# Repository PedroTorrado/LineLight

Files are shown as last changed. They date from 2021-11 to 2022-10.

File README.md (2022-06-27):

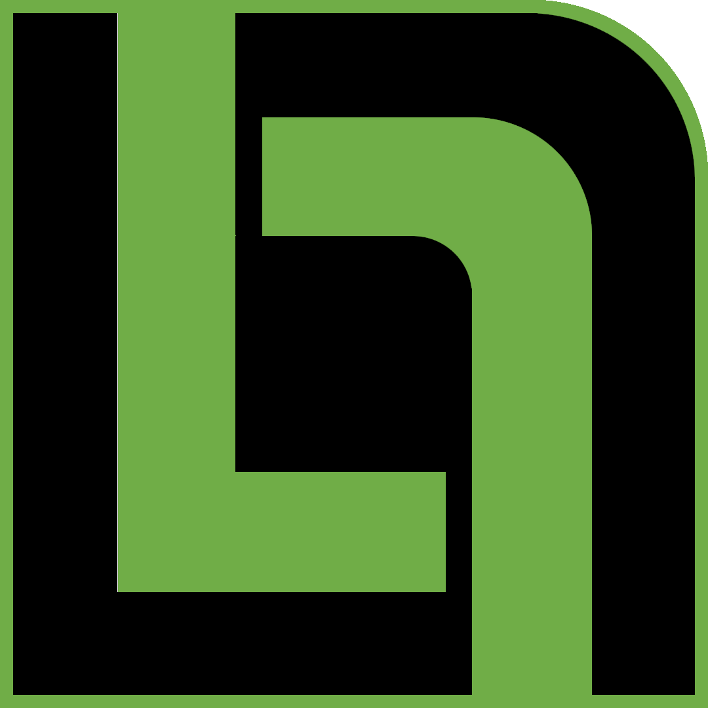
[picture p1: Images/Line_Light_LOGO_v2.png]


# LineLight

## Introduction

This project was created with the objective of creating a safer environment for all means of transport and vehicles in the streets.

This should be accomplished by having a device that helps drivers of means of transportation without turn signals (blinkers), 
through the use of LEDs controlled by the user which will signal the intention of the user to turn or to change lanes.

A big part of traffic safety or road safety is good communication between the drivers of all the different vehicles and/or means of transportation. This "good communication" means only, communication made in a way that everybody can easily and quickly realize the intentions of the drivers around them, so they can make the best decisions to keep the other drivers and themselves as safe as possible.

However, in our day to day, we constantly come across vehicles that do not have light signals, which makes its ways of signalling a lot less clear and safe (especially in darkened environments such as tunnels and during the night). And that's why this project has been created, so that, those types of means of transportation have a good and feature full way of coexisting in the streets with all other vehicles and/or means of transportation.

---

## Objectives

The device, apart from it's basic functionality should be:

  1. Compact and storable when not in use;
  
  2. Usable with various types of transport:
  
    -Bicycle;
    -Skateboard;
    -Scooter; 
    -etc.
    (And electric variants of the same)
    
  3. Intuitive to use;
  
  4. Alerts the user in case the action intended to signal doesn't work as intended;
  
  5. Resistance to harsh environments;
  
  6. Aesthetic and discrete;
  
  7. Easy to repair without full replacement;
  
---

To complete all these objectives, various functionalities are required to implement, such as,
wireless communication between a controller (Transmitter) and the main device (Reciever), which I called Controller and MainBoard throughout my files. (Objectives 1, 2 and 3)

---

For the 4th objective to be reached it's important that the components are able to have bidirectional communication so that once a signal is sent by the transmitter, the receiver can send a  signal back confirming it is working as intended.

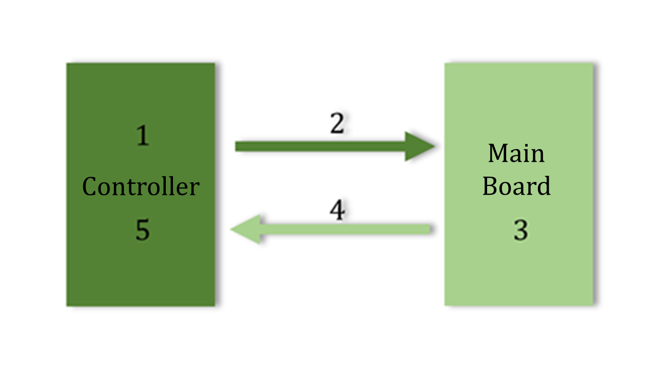
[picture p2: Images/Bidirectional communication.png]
biderectional


Caption:

  1. An action is taken on the controller by the user creating a signal;
  2. That signal is sent to the MainBoard;
  3. The Board acts as intended by the user;
  4. A signal is sent by the MainBoard;
  5. The controller confirms to the user that the board is acting as intended. 
  
But why is this function so important? Well, let's imagine for a moment a scenario where the user sends a signal to the MainBoard thinking he is signalling the vehicles around him that he is going to turn, and for some (exceptional) reason the MainBoard doesn't receive the signal, however, the user acts thinking that it did and that the drivers around him are aware that he is going to take his turn. The user is put in a very dangerous situation, way more dangerous than if he just used hand signs to signal the drivers around him. 

This way, by having a way to check if his signal has created the action he intended to, he can make his turn way more safely and be aware in case it doesn't so he can still use hand gestures to aware the drivers around him of his intentions (to turn in this case).

---

Briefly, the 5th objective is hinting at the importance that the device is not only well constructed but also (and very importantly) water-resistant because this device is supposed to be used outside while riding no matter the weather, and the worst the weather the more important that a device like this works flawlessly. Therefore it's really important to make sure that the device is made in a way that prevents water to enter into contact with the contacts from the PCB and with the battery itself. Since this is also related to the use and feel of the final device this is also related to the 6th objective. 

---

The 7th and last objective (defined until now), is related to the reparation of the device in case something is no longer functional, for this the device should be made modular so that in case some part of it breaks it's possible (and) easy to replace it and therefore fix the device.

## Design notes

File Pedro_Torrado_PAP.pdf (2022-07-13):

# RELATÓRIO DE PROJETO DE APTIDÃO PROFISSIONAL

# LINE LIGHT

## PEDRO ESPANHA TORRADO DA SILVA ALUNO Nº: 2219063

## PROFESSOR ORIENTADOR: ANTÓNIO BRANCO

## TURMA DE GESTÃO DE EQUIPAMENTOS INFORMÁTICOS (TGEI_19)

TRIÉNIO
– 2019/2022

– ÉPOCA NORMAL
RELATÓRIO DE PROJETO DE APTIDÃO PROFISSIONAL

1

TRIÉNIO – 2019/2022 – ÉPOCA NORMAL 2

## 1.Í ndice

### 1. Índice | 2

### 2. Introdução | 3

### 3. Objetivos de Sustentabilidade ONU | 4

### 4. Calendarização do Projeto | 5

### 5. Funcionalidades do Dispositivo | 6

### 6. Componentes Necessários e Custos do Desenvolvimento | 8

### 7. Circuitos a ser utilizados | 10

### 7.1 Comando | 10

### 7.2 Placa Central | 13

### 7.3 LEDs | 14

### 8. Programa | 18

### 8.1 Comando | 18

### 8.2 Placa Central | 25

### 9. PCBs | 28

### 9.1 Comando | 28

### 9.2 Placa Central | 30

### 9.3 LEDs | 31

### 10. Modelos 3D | 32

### 10.1 Comando | 32

### 10.2 Placa Central | 37

### 10.3 Piscas | 40

### 10.4 Fivela | 42

### 11. Implementação | 44

### 12. Componentes | 46

### 13. Ficheiros em Anexo | 48

### 14. Índice de Imagens | 49

3

## 2.Íntroduçã o

Ao longo deste trabalho tive como objetivo desenvolver um produto que tenha como função facilitar e tornar mais segura a utilização de veículos sem sinais luminosos.
Grande parte da segurança rodoviária baseia-se na comunicação entre condutores dos diferentes veículos de forma que qualquer possível interação ocorra da maneira mais segura possível e que se possa evitar qualquer mal-entendido, criando assim um ambiente em que todos os condutores se sintam seguros.
Contudo, no nosso dia-a-dia, podemos encontrar muitos meios de transporte que coexistem na via pública e que não possuem elementos luminosos de sinalização. Em vez disso, estes condutores utilizam sinais gestuais caso tenham a intenção de alterar de via, realizar uma mudança de direção ou diminuir a velocidade do veículo, mas estes, obviamente, apresentam vários problemas quando comparados com sinais luminosos, principalmente em situações de pouca luminosidade do ambiente, como condução durante a noite ou durante o atravessamento de uma passagem inferior. Como solução para este problema decidi começar a desenvolver o produto a que chamei de Line Light.
Começando pelo nome, decidi chamar ao produto Line Light dada a sua função, sendo esta possibilitar a utilizadores de meios de transporte que não possuem sinais luminosos (Light significando Luz em inglês) a utilização dos mesmos de forma a indicar o trajeto para onde o sujeito se destina (Line tendo o significado de linha, fila ou reta em inglês).

4

## 3.Objetivos de Sustentãbilidãde ONU

Este projeto foi desenvolvido tendo em consideração um conjunto de objetivos de desenvolvimento sustentável (ODSs).

Os Objetivos de Desenvolvimento Sustentáveis são compostos por 17 objetivos e 169 metas que a ONU (Organização das Nações Unidas) pretende atingir até 2030 e estas foram criadas durante a Cúpula das Nações Unidas sobre o Desenvolvimento Sustentável em setembro de 2015 (https://news.un.org/pt/tags/cupula-das-nacoes-unidas-para-sobre-o-desenvolvimentosustentavel).

O meu projeto engloba os segintes ODS:

03 – “Saúde e bem-estar: assegurar uma vida saudável e promover o bem-estar para todos, em todas as idades.” Uma vez que tem como objetivo evitar acidentes rodoviários e assim preservar a saúde e bem-estar de qualquer utilizador de veículos sem indicadores luminosos e também das pessoas que o rodeiam.
09 – “Inovação infraestrutura: construir infraestrutura resiliente, promover a industrialização inclusiva e sustentável, e fomentar a inovação.” Todo o projeto é composto pelo desenvolvimento de novos produtos que funcionam à base de baterias, de forma sustentável, sendo possível utilizar materiais sustentáveis para a produção de alguns dos componentes.
12 – “Consumo e produção responsáveis: assegurar padrões de produção e de consumo sustentáveis.” O projeto foi desenvolvido tendo em atenção que teria que ser de fácil reparação, sendo assim possível reparar o dispositivo sem contribuir para o aumento dos resíduos eletrônicos.

Figura 1 - Objetivos de Desenvolvimento Sustentável

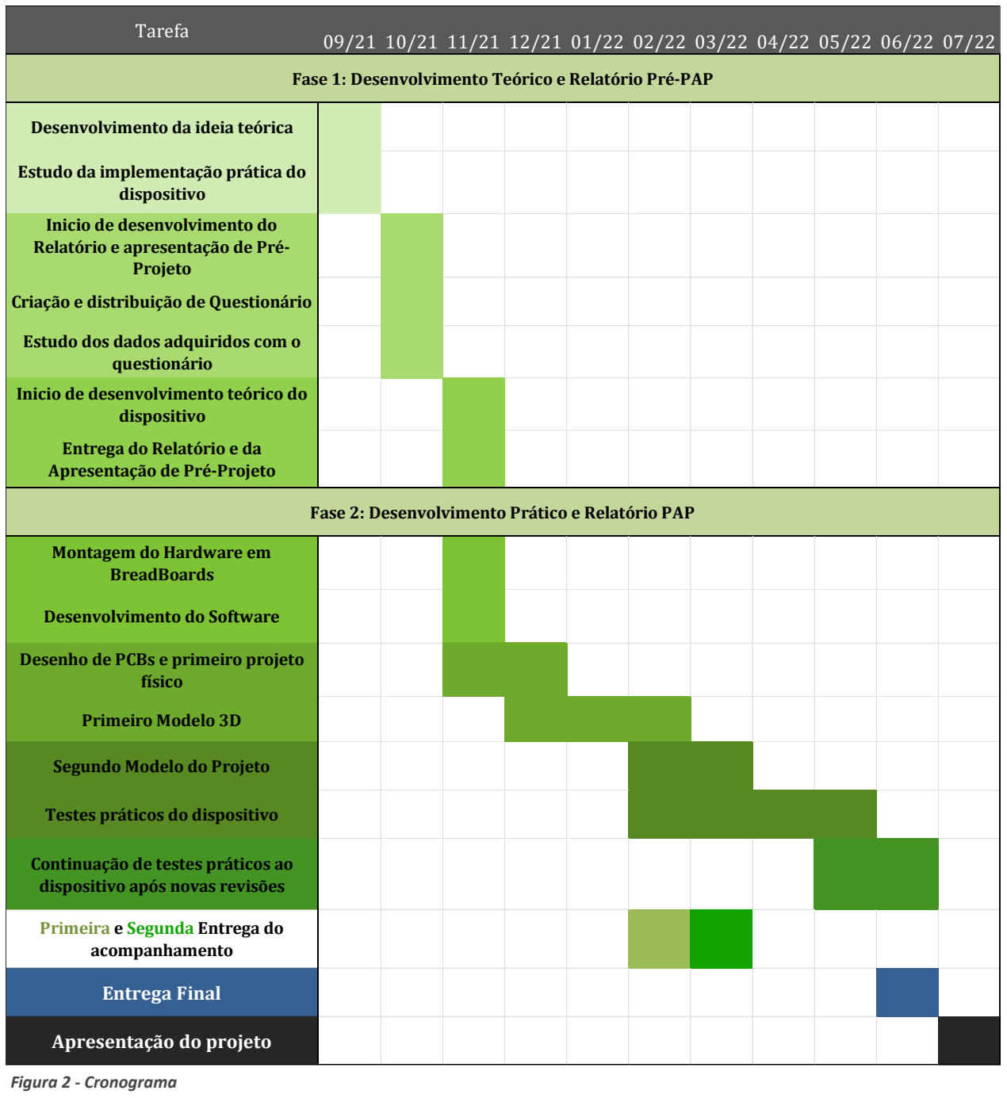
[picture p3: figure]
Desenvolvimento da ideia teórica; Estudo da implementação prática do dispositivo; Inicio de desenvolvimento do Relatório e apresentação de Pré- Projeto; Criação e distribuição de Questionário; Estudo dos dados adquiridos com o questionário; Inicio de desenvolvimento teórico do dispositivo; Entrega do Relatório e da Apresentação de Pré-Projeto; Montagem do Hardware em BreadBoards; Desenvolvimento do Software; Desenho de PCBs e primeiro projeto físico; Primeiro Modelo 3D; Segundo Modelo do Projeto; Testes práticos do dispositivo; Continuação de testes práticos ao dispositivo após novas revisões; Primeira e Segunda Entrega do acompanhamento; Entrega Final; Apresentação do projeto; Figura 2 - Cronograma

5

## 4. Cãlendãrizãçã o do Projeto

A Calendarização pode ser verificada no ficheiro 2, referido nos ficheiros em anexo.
Algumas destas datas não coincidiram com as datas planeadas inicialmente, uma vez que foi criada uma segunda versão do dispositivo após testes iniciais.
Tarefa | 09/21 10/21 11/21 12/21 01/22 02/22 03/22 04/22 05/22 06/22 07/22
| Fase 1: Desenvolvimento Teórico e Relatório Pré-PAP

Fase 2: Desenvolvimento Prático e Relatório PAP

6

## 5. Funcionãlidãdes do Dispositivo

Ao planear este projeto comecei por refletir se este projeto era interessante para outros possíveis utilizadores e para isso decidi criar um questionário, com perguntas relacionadas com o possível interesse por este tipo de dispositivo, e o tipo de funcionalidades que poderia introduzir chegando à conclusão de que havia um conjunto de funcionalidades que queria que fizessem parte do dispositivo, sendo essas:

1. Ter a capacidade de realizar sinalização luminosa antes do utilizador realizar uma mudança de direção ou de via.
2. Ser um dispositivo compacto e portátil, mesmo quando não está em uso;
3. Ser um dispositivo versátil de forma a poder ser utilizado com um conjunto de meios de transporte;
4. Ser um dispositivo de utilização intuitiva e natural;
5. Ser um dispositivo seguro e que seja capaz de avisar o utilizador caso haja algum erro e o seu sinal não seja transmitido da forma pretendida;
6. Ser um dispositivo que tenha resistência a condições climatéricas exteriores adversas e longa durabilidade;
7. Ser um objeto estético e discreto;
8. Ser possível a reparação sem ser necessário substituir todo o dispositivo.

De forma a ir ao encontro destes requisitos decidi utilizar dois dispositivos separados, um comando e um conjunto central (composto por uma placa central ligada aos 2 piscas) com comunicação sem fios entre si, de forma a satisfazer os pontos 2, 3, 7. De forma a ter em conta o ponto 5, é necessário que estes dois dispositivos possam comunicar entre si para que possam fazer o seguinte sistema de verificação.

1 – Uma ação do utilizador gera um sinal;
2 – Esse sinal é transmitido para a placa central;
3 – A placa central produz a ação pretendida pelo utilizador;
4 – Um sinal é emitido pela placa central para o Comando;
5 – O comando produz uma ação que demostra ao utilizador que a sua ação gerou a reação pretendida pela placa central.

7

Sendo este dispositivo sem fios, tive que realizar diversos testes com várias formas de comunicação sem fios, entre as quais:
Radiofrequência – Não era possível comunicação bidirecional a não ser que fossem utilizados 4 módulos, um recetor e um emissor por dispositivo. Para testes utilizei dois módulos de 433MHz (Componente 1.
Infravermelhos – Para além de ter o mesmo problema da Radiofrequência, estes têm um sinal muito direcionado e que não pode ser obstruído uma vez que este sinal é enviado por sinais luminosos (Componente 2 e 3).
A última opção, que testei e aquela que acabou por ser utilizada foram módulos Bluetooth HC–05 e HC-06 (Componente 4). Uma vez que a partir de Bluetooth é possível ter comunicação bidirecional e sendo estes Bluetooth v2.1 estes têm um alcance registado de 100 metros. Para além disso, escolhi estes módulos pois eles são os indicados para utilização SPP (Serial Port Protocol) o que facilita bastante a sua implementação neste projeto. Uma vez que o dispositivo funciona por Bluetooth este poderia também funcionar a partir de conexão ao telemóvel o que é possível e bastante fácil de conectar, desde que se utilizem aplicações que também utilizam o protocolo SPP. Assim é possível também desenvolver uma aplicação especificamente para este propósito, apenas não foi feito por não ser o foco deste projeto.

Considerando o ponto 6, é necessário ter o dispositivo o mais isolado o possível (tendo em conta a funcionalidade) do exterior, para isso decidi que a melhor forma de carregar o dispositivo é por Indução Eletromagnética. Apesar de ter criado a possibilidade de o fazer a partir de contactos elétricos, esses acabaram por não ser utilizados uma vez que era difícil isolar os mesmos do interior da caixa do dispositivo, mas com melhores ferramentas de produção seria possível e PCB tem essa capacidade de expansão num modelo futuro.

Tal como o carregamento, é necessário que a interação com o comando se encontre isolada do exterior. Este foi um dos maiores problemas que encontrei quando estava a projetar o funcionamento do mesmo. Poderia ser feito de várias formas, mas grande parte envolvia desenhos CAD demasiado desenvolvidos e com tolerâncias demasiado apertadas para as minhas competências e para as ferramentas que tenho à minha disposição. Assim optei pela utilização de sensores de campo electromagnéticos (Hall Effect Sensor) e Ímanes de Neodímio. Este método pouco convencional torna possível a existência de uma parede entre o dispositivo e a forma de interação com o mesmo.

8

## 6. Componentes Necessã rios e Custos do Desenvolvimento

De forma a organizar os componentes em questão, dividi-os em tabelas:

Componentes de teste e produção | Quantidade | Número de Componente
Breadboard | 3 | 6
Arduino Nano | 2 | 7
Cabo Usb 2.0 mini B | 2 | 8
Carregador de baterias de lítio tp4056 | 2 | 9
Baterias de lítio mr18650 (3.7v e 2200mAh) | 2 | 10
Cabos de conexão | 30 | 11
Arduino Uno | 1 | 12
FTDI FT232RL | 1 | 13
Comando e placa central | Quantidade | Número de Componente
Módulo Bluetooth HC-05 (configurado em modo 0) | 1 | 4
Módulo Bluetooth HC-06 | 1 | 5
LEDs (Díodos emissores de luz) | 4 | 14
Transístores PNP | 2 | 15

Indicadores Luminosos de Direção (2 conjuntos) Quantidade Número de Componente
Temporizador NE555 (NE555 Timer) | 2 | 16
CD4017 Contador de Década (CD4017 Decade Counter) | 2 | 16
Condensadores de diversos valores | 4 | 17
Resistências de diversos valores | 10 | 18
LEDs (Díodos emissores de luz) | 10 | 14
Díodos | 1 | 19

9

Para calcular o preço de materiais na produção deste projeto, criei um ficheiro BOM (Bill Of Materials ou Lista de Materiais), em anexo, e que será atualizado ao longo deste projeto, de forma a manter o preço de produção sempre atualizado, uma vez que pretendo adicionar vários componentes a esta lista e alterar outros.
As tabelas de preços por componente podem ser reduzidas em tabelas de preço por dispositivo, como a que está apresentada abaixo.
No ficheiro em anexo pode verificar-se que grande parte dos componentes são ficheiros SMD, pois a certa altura no desenvolvimento do projeto apercebi-me que, para certos circuitos e alguns dos dispositivos, era mais prático, sendo que o preço por dispositivo reduziu drasticamente, mas componentes SMD têm que ser comprados em massa, o preço apresentado na tabela abaixo é o preço de cada um dos dispositivos com esses componentes, sendo que a encomenda de todos os componentes SMD (que se podem verificar mais tarde nos circuitos) para um comando ficou exãtãmente 8.74€ (excluindo portes).
Dispositivos | Preço (€) de | Preço (€) em
| Protótipo | massa
Placa Central (Main Board) | 14.72 | 5.61
Pisca (Blinker) | 1.83 | 1.83
Pisca (Blinker) | 1.83 | 1.83
Comando (Controller) | 16.89 | 8.21
Total* | 35.27 | 24.48

Contudo, esses valores aplicam-se apenas a um conjunto de componentes e não ao preço de desenvolvimento deste projeto. É difícil dizer exatamente o valor gasto no desenvolvimento deste projeto, considerando os componentes que já tinha em minha posse e à quantidade de material gasto na produção de protótipos. Mas, tendo em consideração os PCBs comprados e os componentes comprados para este projeto. Este fica aproximado do valor de 363.34€. Os valores podem ser verificãdos no ficheiro “Encomendãs” em anexo.

10

## 7. Circuitos ã ser utilizãdos

Os circuitos nas imagens seguintes estão divididos por secções. Para auxiliar a verificação dos circuitos na íntegra, que é mais fácil de seguir e compreender, estes encontram-se na pasta “Circuitos”.

## 7.1 Comãndo

Começando pelo circuito de ATMEGA328P, este necessita de 2 condensadores de 22pf e um oscilador de cristal de 16Mhz, conectado aos pinos 9 e 10 como representado na figura 4 , de forma que este funcione com um clock externo e assim se possam utilizar funções como millis() e delay(). Além disso, o microprocessador encontra-se conectado a um condensador de 100nF nas entradas a GROUND e VCC, para filtragem de alta frequência e evite variações de tensão no microprocessador. Encontra-se também conectado a uma resistência 10kΩ no pin de RESET conectado a VCC de forma a que este não esteja em RESET constante. O microprocessador está ainda desenhado de forma a poder conectar-se um FT232R, um programador de microprocessadores. Os pinos serão usados para fazer upload do software no microprocessador. O LED indica quando o microprocessador está ligado.

Figura 4 - ATMEGA328P Comando

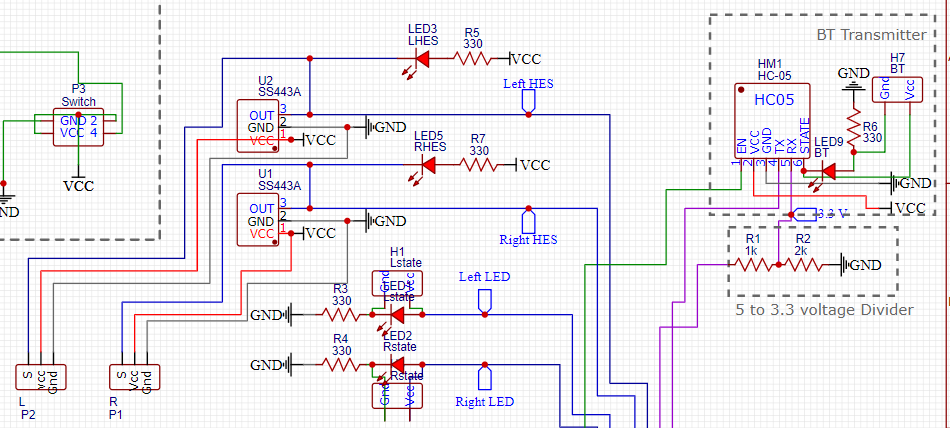
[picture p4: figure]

11

Figura 5 - Circuito de SS443A e HC-05

As saídas do microprocessador, sinalizadas a azul, estão por sua vez ligadas a dois SS443A (Hall Effect Sensors) conforme apresentado na figura 5 e estes têm as suas saídas ligadas a pinos ordenados Signal, VCC e GND, para ser utilizável com módulos a3144 (Componente 20). E o seu output está também ligado a LEDs com as respetivas resistências necessárias para que ao haver um sinal, haja um sinal visível, neste caso a luz destes LEDs.
Se verificarmos o lado direito da imagem acima, podemos ver um módulo HC05 (Programado como MASTER) e com os pinos verdes e roxos conectados, como se pode ver nas duas figuras acima (4 e 5). É importante, ao utilizar um componente como este, que só suporta entrada de sinal a 3.3V, criar um divisor de tensão como o apresentado na figura, podendo assim ligar este a um circuito de 5V sem haver o perigo de estragar o mesmo, principalmente se este estiver a receber sinais mais longos.

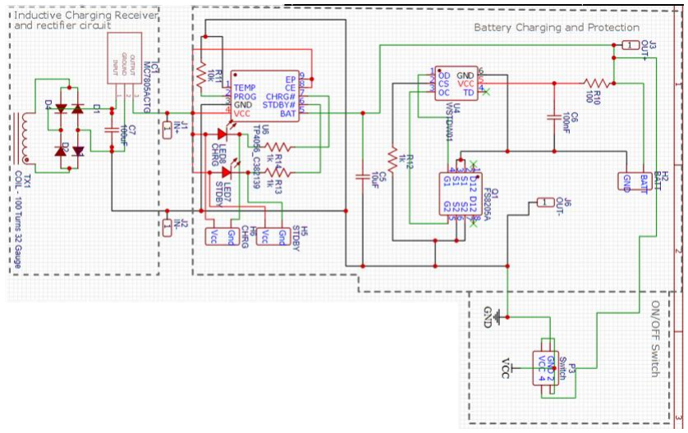
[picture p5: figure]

12

Esta parte do circuito é a parte responsável por carregar a bateria. Se olharmos para o circuito na figura 6 da esquerda para a direita, este começa por uma bobina de 100 voltas de um fio de cobre de 0.27mm, que, na proximidade de um circuito que crie um campo de indução eletromagnética, faz com que haja um input em corrente alternada no circuito. Para tornar esta corrente alternada em corrente contínua é utilizado um conjunto de díodos de forma a criar um retificador de ponte completa e um condensador de 100uF para que a corrente em pulsos do retificador se torne o mais próximo possível de corrente contínua. O funcionamento do rectificador encontra-se representado nas figura 7.

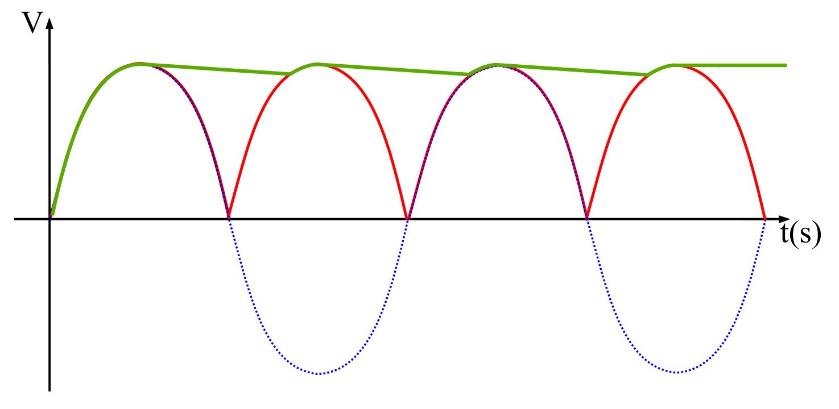
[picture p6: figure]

É preciso ter em atenção que, ao entrar no circuito, a corrente não está a 5V nem a nenhum valor constante, uma vez que esse valor varia conforme o quão próxima a bobina deste circuito se encontra do carregador. De forma a que este valor, agora em corrente contínua, seja

Figura 7 - Circuito de Carregamento

Figura 6 - Corrente Alternada (Azul), Sinal Retificado (Vermelho), Corrente Contínua (Verde)

13

constantemente 5V, é necessário um regulador de tensão (neste caso utilizei um mc7805). Agora a 5V este o circuito passa por um TP4056 (existem vários módulos com este circuito integrado que servem exatamente para esta aplicação e é bastante fácil encontrar online) que é um circuito integrado para carregamento de baterias de Li-ion (Ião de Lítio). Este está conectado, conforme o recomendado na sua ficha de dados, a um circuito fs8205a, que é um MOSFET NPN, e que é utilizado nesta configuração de forma a funcionar como um circuito de proteção da bateria, assim como o circuito integrado WSTDW01 que tem como característica a proteção contra sobrecarga e gera um clock interno, facilitando a sua implementação num circuito como este. De seguida, este circuito termina em 4 pinos, 2 para a saída de corrente, para que o circuito enquanto carrega utilize a corrente diretamente deste circuito, em vez de descarregar a bateria à qual estão ligados os outros 2 pinos. Tudo isto ligado a um botão interruptor que permite ligar e desligar este circuito.

## 7.2 Plãcã Centrãl

Na placa central o circuito de carregamento da bateria é exatamente igual ao do comando e o seu circuito de microprocessador também é muito parecido, não havendo, deste modo, necessidade de o demonstrar. A única diferença entre os dois é o que se faz com esses recursos.

Figura 8 - Circuito Comando

Como podemos verificar na imagem em cima, este circuito também se encontra conectado a um HC05. Contudo, este tem que se encontrar na definição SLAVE para que funcione corretamente, para esse resultado pode também utilizar-se apenas um HC06, uma vez que este não permite a alteração de estado para MASTER e por isso não pode ser utilizado no comando. De resto essa parte do circuito também é idêntica. Sendo apenas diferente a parte de OUTPUT do circuito, o qual é apenas 2 transístores conectados e dois pinos cada para cada um dos circuitos de funcionamento dos LEDS (havendo um terceiro apenas constantemente ligado que pode ser utilizado para testes ou para uma 3ª luz).

14

## 7.3 LEDs

Sendo o meu objetivo tornar este produto modular, tentei evitar a utilização de microcontroladores por componente modular, para além dos dois necessários para a comunicação entre o comando e a placa central. Assim, optei por desenvolver os circuitos restantes, sendo estes os circuitos dos indicadores luminosos de direção, apenas em hardware (como se pode verificar na tabela com o mesmo nome apresentada no tópico anterior) e sem qualquer software.
Acrescentando a isso, queria ainda que estes não piscassem apenas (uma vez que estarão próximos um do outro, tendo apenas aproximadamente a largura da bicicleta como superfície de apresentação) mas representassem a direção através de uma animação, deixando assim clara a direção que o utilizador pretende indicar.

Para essa animação decidi utilizar circuito integrado com função oscilador e um contador de década, de forma a criar um circuito com a animação desejada.

Circuito Integrado com função oscilador - NE555P

Contador de década - CD4017BE

Assim, seguindo as especificações dos circuitos integrados e ficha de dados fornecida pelas empresas fornecedoras de cada um desses produtos, desenvolvi o esquema do circuito obtendo o circuito que irei utilizar e que vou proceder a explicar.

Sabendo os componentes a utilizar, como demonstrados na figura que veremos mais tarde (figura 12), podemos utilizar a fórmula do circuito integrado NE555P, presente nos documentos do mesmo, para calcular a frequência do pulso de sinal do mesmo, sendo essa:

Figura 9 - NE555P

Figura 10 - CD4017BE

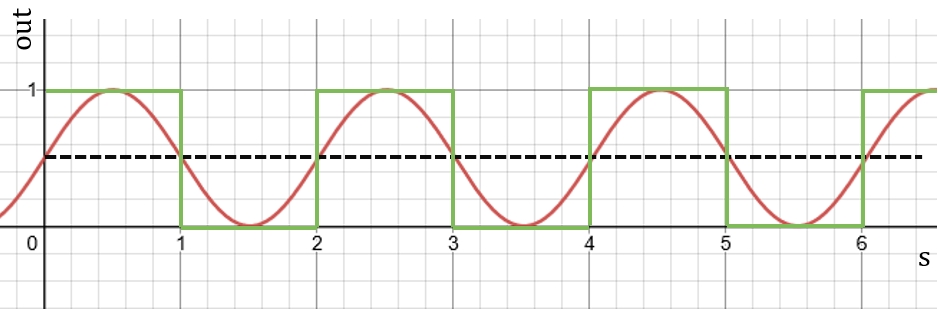
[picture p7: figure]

15

f = 1.44/(R4+2xR2) * C1
f = 1.44/(10k+2*100k) * 2.2uF

E produzindo, assim, um resultado de:
f = 3.123Hz

E sabendo que o período é o inverso da frequência, obtemos:
T = 0.320s

Os restantes valores possíveis de calcular estão organizados no ficheiro 5 em anexo.

Este gráfico (figura 12) representa a conversão de um gráfico sinusoidal (representado a vermelho) do circuito integrado num gráfico do output digital (representado a verde) do mesmo circuito no qual o limite é a metade da amplitude da sinusoidal (representada pelo tracejado a preto).

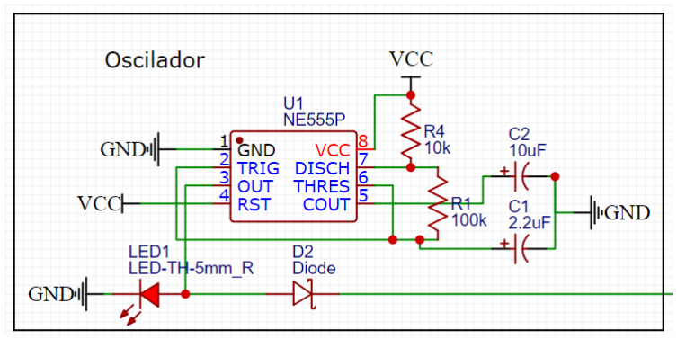
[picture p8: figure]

Figura 12 - Circuito de Contador de Década e Output do sistema

Figura 11 - gráfico de output do circuito integrado NE555P

16

Figura 14 - Circuito com função de Oscilador

Figura 13 - Circuito completo de Indicador Luminoso de Direção

17

Este circuito funciona da seguinte forma: O contador de década altera o seu pin de Output cada vez que recebe um sinal no seu pin de Clock, e uma vez que este está conectado ao pin de Output de um circuito de oscilador, o contador de década altera o seu Output conforme a frequência definida pelo mesmo (3.123Hz, como definimos anteriormente), criando um ciclo estável que pode ser usado como animação e na qual será aceso uma fita led por cada Output, simulando assim o movimento dos leds e descrevendo o movimento que o utilizador pretende realizar. Este circuito não foi o circuito final e tiveram que ser acrescentados transístores aos outputs que estavam, por sua vez, ligados diretamente à entrada da Placa Central. Deste modo, o sinal do contador de década pode ser utilizado como pin central destes transístores e assim os leds ignoram por completo a passagem de tensão pelos restantes componentes e podem ligar-se com toda a corrente e tensão que lhe é fornecida pela Placa Central. Paara além disso, agora todos os Leds estão com uma ligação a GROUND comum o que torna possível utilização de menos cabos entre componentes, sendo este o circuito final dos LEDs.

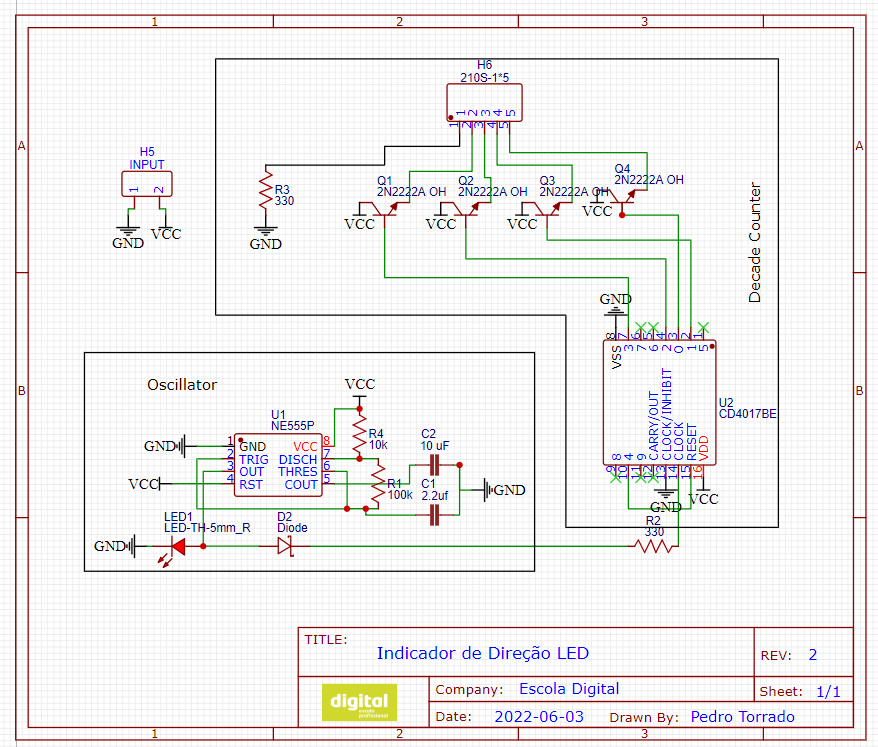
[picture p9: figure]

Figura 15 - Circuito Piscas Final

18

## 8.Progrãmã

A programação destes circuitos foi desenvolvida ao mesmo tempo que os circuitos foram desenhados, mas após ter explicado e demonstrado a organização do circuito, os pinos do microprocessador a ser utilizado e os componentes em questão, será mais fácil imaginar a forma como o mesmo funciona. Para fazer este programa utilizei o editor de texto Atom como IDE utilizando PlatformIO para conseguir fazer upload de código e utilizar o Monitor de porta Serial. Estes ficheiros encontram-se na pasta Código. Tendo isso em consideração:

## 8.1 Comãndo

#include <Arduino.h>

#include <SoftwareSerial.h>

SoftwareSerial bt(2, 3); //RX, TX

#define right_hes 5

#define left_hes 4

#define bt_enable 9

#define left_led 8

#define right_led 7

int left_state = 1;
int right_state = 1;
int verification_code;

Figura 16 - Bloco 1 de código comando (linha 27 a 40)

Como qualquer código de C++, o código começa por incluir as bibliotecas que vai utilizar, uma vez que estamos a utilizar um processador ATMEGA, de forma a podermos utilizar as suas capacidades da mesma forma que um arduino, temos que incluir a biblioteca Arduino, para além disso é importante incluirmos a biblioteca SoftwareSerial uma vez que com esta podemos passar os pinos RX (recetor) e TX (transmissor) para pinos diferentes dos próprios. Para isso, é importante não utilizar os pinos RX e TX integrados no microprocessador uma vez que se tivermos estes conectados a um componente, não será possível programar o microprocessador. Para definir quais são os pinos que pretendemos utilizar podemos verificar no nosso circuito, estes estão conectados ao módulo HC05 e são o pino 2 para recetor e 3 para o transmissor, isto pode tornar-se um pouco confuso uma vez que têm que ser o oposto daqueles no módulo Bluetooth, mas é fácil de perceber ao sabermos para que servem estes pinos. O pino TX ou transmissor, como o nome indica envia um sinal, portanto este tem que estar ligado a um pino RX ou recetor de forma a receber esse mesmo sinal. Assim, o RX do microcontrolador tem que estar conectado a TX do HC05 e RX do microcontrolador tem que estar conectado a TX do HC05. Portanto, apesar da primeira reação poder ser ligar os pinos

19

com os mesmos nomes, percebendo o conceito rapidamente percebemos a razão pela qual isso não está certo. Agora, para definirmos no código quais são esses pinos, utilizamos a função SoftwareSerial (da biblioteca com o mesmo nome) e definimos o nome do dispositivo que estamos a atribuir neste caso bt() dentro dessa função indicamos os pinos como se pode verificar no excerto do programa.

Após esta fase, são definidos os pinos para os sensores de campo eletromagnético (right_hes. left_hes), outro conectado à saída STATE do HC05 (bt_enable), e dois para leds com o objetivo de demonstrar a verificação de sinal enviado para a placa central (left_led, right_led). De seguida são definidas 3 variáveis globais de forma a que funcionem em qualquer função do programa, sendo essas left_state e right_state que têm como objetivo definir em que estado se encontram os leds left_led e right_led. Para além disso, é necessário criar a variável verification_code para usar mais tarde.

20

Depois do primeiro bloco de código, temos a função setup() sendo esta a função chamada no início de um programa e a forma standard de configurar o modo dos pinos. Ao longo desta configurei então cada um dos pinos necessários para os o funcionamento correto do programa, e isso é feito utilizando pinMode() e dentro desta indicamos o pino a que nos queremos referir e após isso se este é INPUT ou OUTPUT sendo INPUT a entrada de um sinal e OUTPUT a saída de sinal, ou de corrente. Para além disso, inicia o Monitor Serial a partir de Serial.begin(9600) sendo 9600 o baud rate do microprocessador e para que assim possamos verificar os processos em questão e facilitar o diagnóstico de problemas. De seguida podemos indicar ao utilizador por Monitor Serial que o programa está a funcionar como pretendido, apresentando essa informação no Monitor Serial como este programa faz com "Start Cntrlr" e "Pairing...", ao vermos isso podemos verificar não só que o microprocessador está a funcionar, mas que o dispositivo ainda se está a conectar (naturalmente uma vez que acabou de se ligar) e uma vez que este estiver conectado irá apresentar "Device Paired" , como veremos.

void setup() {
//Bluetooth RX and TX defined pinMode(2, INPUT);
pinMode(3, OUTPUT);

//HC06 enable pin set to high pinMode(9, OUTPUT);
digitalWrite(bt_enable, HIGH); bt.begin(9600);

//Hall Effect Sensors defined pinMode(right_hes, INPUT); pinMode(left_hes, INPUT);

//Verification LEDs defined pinMode(left_led, OUTPUT); pinMode(right_led, OUTPUT);

Serial.begin(9600);
Serial.println("Start Cntrlr");

Serial.println("Pairing..."); }

Figura 17 - Bloco 2 de código comando (linha 42 a 64)

21

De forma a ser possível a verificação de sinal para a qual era importante a comunicação a duas vias, que referi múltiplas vezes no capítulo 5 (Funcionalidades do Dispositivo), criei a função verification() cujo propósito é exatamente demonstrar uma verificação de sinal através dos LEDs conectados aos pinos de verificação (left_led e right_led). Mas como se faz?

No início da função, o programa verifica se houve alguma alteração de sinal no tipo de comandos enviados pelo outro dispositivo, isto é feito a partir da função bt.available() que apenas demonstra valores maiores de 0 quando um sinal é enviado quando não é, envia 0. Após fazer essa verificação iguala-se o valor enviado pelo outro dispositivo (lido com bt.read()) à variável verification_code,

void verification(){

if (bt.available()>0) {
verification_code = bt.read();
Serial.println(verification_code); //Shows the byte sent from the slave for trou bleshooting

if(verification_code == 10){
digitalWrite(left_led, HIGH);
//Shows what type of confirmation it has recieved, for troubleshooting in case of led problems
Serial.println("left_confirmed_high");
}
else if(verification_code == 11){ digitalWrite(left_led, LOW); Serial.println("left_confirmed_low"); }
else if(verification_code == 20){ digitalWrite(right_led, HIGH); Serial.println("right_confirmed_high"); }
else if(verification_code == 21){ digitalWrite(right_led, LOW); Serial.println("right_confirmed_low"); }
else if(verification_code == 91){ Serial.println("Device Paired");
}

else{
Serial.println("Input error : Not intended result or verification"); }
}
else{
verification_code = "";
}
}

Figura 18 - Bloco 3 de código comando (linha 66 a 100)

22

que tinha sido criada no primeiro bloco de código. Se não foi enviado nenhum sinal, esta variável é iguãlãdã ã “” ou sejã, ã nenhum valor inteiro.
Tendo esta variável, o programa verifica se é igual a um número de um conjunto de números, cada um com um significado.
CÓDIGO | PISCA | ESTADO
10 | Esquerdo | Ligado
11 | Esquerdo | Desligado
20 | Direito | Ligado
21 | Direito | Desligado
91 | Nenhum | Dispositivos Conectados

Figura 19 - Tabela de Códigos de Verificação

A verificação do resultado pretendido ao enviar-se um sinal (que vamos ver como é feito no próximo bloco) é assim feita apenas por receber um sinal do outro dispositivo ao reproduzir a ação produzida. E se o código que receber não for um dos pretendidos podemos verificar esse erro a partir do Monitor Serial com o erro:

"Input error : Not intended result or verification"

E quando o resultado é o pretendido pode verificar-se uma mensagem como:

"right_confirmed_high"

23

Na função loop() ao haver um sinal por parte do outro dispositivo, a função verification() é chamada de forma a fazer a verificação como explicada antes. Após isso são utilizadas as variáveis left_state e right_state que são igualadas a digitalRead(left_hes) e digitalRead(right_hes) sendo estes os valores lidos pelos sensores SS443A, que ao apresentarem HIGH ou 1, sabemos que não estão a detetar um campo eletromagnético e quando apresentam LOW ou 0, sabemos que estão a detetar um campo eletromagnético. Ou seja, neste caso 0 ou LOW significa que o utilizador quer alterar o estado do pisca do mesmo lado e quando está em HIGH significa que o utilizador não o acionou. Após esse processo existe em comentário: //Serial.println(right_state);
Este deve ser utilizado, retirãndo “//” para verificar o estado do sensor direito de forma a verificar que o microprocessador está a ler os valores de pelo menos um dos sensores.

void loop() {

if (bt.available()>0) {
verification();
}

left_state = digitalRead(left_hes); right_state = digitalRead(right_hes);
//Show the output in Serial for troubleshooting //Serial.println(right_state);
if (Serial.available()){
bt.write(Serial.read());
}

if (right_state == LOW) {
Serial.println("Right");
//Show the output in Serial for troubleshooting //Serial.println('2');
bt.write('2');
delay(200);
verification();
delay(800);
}

if (left_state == LOW) {
Serial.println("Left");
//Show the output in Serial for troubleshooting //Serial.println('1');
bt.write('1');
delay(200);
verification();
delay(800);
}
}

Figura 20 - Bloco 4 de código comando (linhas 102 a 135)

24

É possível passar qualquer input feito no Monitor Serial com:

Facilitando o diagnóstico de problemas, uma vez que assim é possível passar informação diretamente para o outro dispositivo, sem ser necessário estar a utilizar os sensores, nem ter os mesmos funcionais. Podendo deste modo verificar se um problema pode existir com o sensor ou com a transmissão de informação.
Sabendo como são definidas as variáveis right_state e left_state o programa tudo o que faz é verificar se estes se encontram no estado LOW e se assim for apresenta essa informação no Monitor Serial apresentando "Right" e "Left" e após isso transmite-se 2 ou 1 para a placa central tendo 2 o significado de direito e 1 o significado de esquerdo (que como podemos verificar na última tabela que foi apresentada, o 1º dígito mantém a mesma organização).
Enviando o sinal, o microprocessador interrompe os processos durante 200ms utilizando a função delay() dando tempo ao outro dispositivo de receber o sinal. Terminados os 200ms inicia a função de verificação para que possa demonstrar que o pisca pretendido se encontra ligado ou desligado conforme o pretendido.

E com isto tem-se o comando. Mas, para ter noção de alguns destes processos é preciso perceber também de onde vêm alguns dos valores que este recebe, como na verificação e o que acontece quando são recebidos os valores enviados pelo comando.

if (Serial.available()){
bt.write(Serial.read());
}

25

## 8.2 Plãcã Centrãl

Esta placa, como já referido tem como objetivo ser o recetor entre os dois piscas e o comando, ou seja, tem como função receber o sinal do comando e controlar o estado dos piscas e se estes se encontram ligados ou desligados, para além disso tem também que enviar o sinal para o comando a verificar o estado dos piscas como referido anteriormente.

Assim como no comando, o início do programa tem como objetivo incluir as bibliotecas necessárias e os pinos para os componentes, sendo esses componentes apenas os pinos aos quais se ligam os circuitos dos piscas e aos quais chamei left_led e right_led. Para além disso, é preciso notar as variáveis definidas aqui uma vez que estas serão explicadas ao longo do programa.

Na função setup() fazemos o mesmo que no comando e definimos se os pinos estão a ser utilizados como entradas ou saídas de sinal e inicia-se a utilização do Monitor Serial.

Figura 21 - Bloco 1 de Código Placa Central (Linha 23 a 37)

#include <Arduino.h>

#include <SoftwareSerial.h> SoftwareSerial bt(3, 2); //RX, TX

#define left_led 7

#define right_led 8

int i;
int left_state = 1;
int right_state = 1;
int lr_state = 0;
int new_left_state = 1;
int new_right_state = 1;
int new_lr_state = 0;
char serial_command;

Figura 22 - Bloco 2 de Código Placa Central (Linha 39 a 50)

void setup() {
pinMode(3, INPUT);
pinMode(2, OUTPUT);

pinMode(left_led, OUTPUT); // sets the digital pin 7 as output pinMode(right_led, OUTPUT); // sets the digital pin 8 as output

Serial.begin(9600);
bt.begin(9600);

Serial.println("Start Blnkrs"); }

26

De forma a controlar o estado dos piscas e se possam enviar os códigos de verificação corretos, foram criadas duas funções leftstate() e rightstate(). Na figura acima temos representada a função leftstate() que tudo o que faz é verificar qual é o estado do respetivo pisca e caso este esteja desligado, envia o código 10 (como verificámos na tabela de códigos de verificação significa LED Esquerdo Ligado), e caso esteja ligado envia o respetivo código de verificação. A função rightstate() faz exatamente o mesmo processo, mas de forma a controlar o lado direito.

A função loop() começa por definir as duas funções referidas anteriormente e para além disso verifica se há algum sinal enviado pelo módulo Bluetooth ou algum sinal dado através de Monitor Serial. Caso haja um deles:

void leftstate(){
if(left_state == 0){
bt.write(10);
Serial.println("Verification Code Sent: 10"); }
else if(left_state == 1){
bt.write(11);
Serial.println("Verification Code Sent: 11");
}
else {
Serial.println("Input error : state was changed but the result isn't valid"); }
}
Figura 23 - Bloco 3 de Código Placa Central (Linha 52 a 64)

void loop() {

//include both functions for verification int leftstate();
int rightstate();

if(bt.available()>0 or Serial.available()){

Figura 24 - Bloco 4 de Código Placa Central (Linhas 82 a 86)

char command = bt.read();
serial_command = Serial.read();

if (command != ""){
Serial.println(command);
}
else if (serial_command != ""){ Serial.println(serial_command); }

27

Figura 25 – Bloco 5 de Código Placa central (Linhas 88 a 103)
É criada uma variável do tipo caractere, chamada command, que é igualada ao sinal enviado por Bluetooth e a variável serial_command, igualada ao sinal dado por Monitor Serial. Se qualquer um dos dois enviar um sinal diferente de “” este é apresentado no Monitor Serial. Depois disso o comando ao receber o código 9 este envia o código 91 para que o comando saiba que se encontram conectados, testando assim também essa conexão.

Ao receber o código 0, 1 ou 2 o programa vai sempre fazer o mesmo processo alterando apenas as variáveis e dispositivos em questão. No exemplo acima está a ser utilizado o pisca esquerdo e de forma a evitar que o programa mude o estado do mesmo e envie sinais de verificação constantemente é necessário utilizar uma variável global que neste caso é new_left_state e que não se altera a não ser que o comando código 1 seja recebido, caso seja, assim como na função leftstate() este verifica o estado do led e caso este esteja ligado faz uma ação e caso esteja desligado faz outra, sendo que em vez de apenas enviar um sinal, este desliga e liga o led, respetivamente.

E assim, muito simplesmente, é possível alterar o estado dos piscas utilizando os sinais enviados pelo comando e é também possível enviar a informação necessária de forma que o mesmo possa demonstrar essa informação.

if(command == '9' or serial_command == '9'){
Serial.println("Device Paired");
bt.write(91); // Verification Code sent to Controller to verify connection leftstate();
rightstate();
}

if (command == '1' or serial_command == '1') {

if (new_left_state == 1) {
digitalWrite(left_led, HIGH); // sets the digital pin 7 ON Serial.println("LEFT_HIGH"); // print on serial monitor the pin mode left_state = 0;
}
else if (new_left_state == 0) {
digitalWrite(left_led, LOW); // sets the digital pin 7 OFF Serial.println("LEFT_LOW"); // print on serial monitor the pin mode left_state = 1;
}
new_left_state = left_state;
leftstate();
}
Figura 26 - Bloco 6 de Código Placa Central (Linhas 144 a 158)

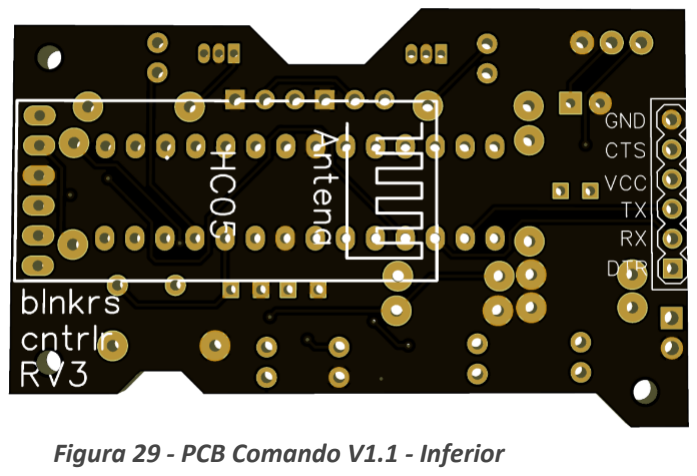
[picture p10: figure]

28

## 9.PCBs

Após desenvolver os desenhos dos circuitos, foi possível desenvolver os PCBs, seguindo as mesmas ligações e sendo o resultado final o seguinte:

## 9.1 Comãndo

O primeiro circuito a ser desenvolvido foi preparado para ser utilizado com uma fonte externa para testes e por isso foi feito sem um circuito de carregamento e proteção da bateria.
Ao desenvolver este PCB decidi também tentar passar o módulo Bluetooth para a camada inferior do PCB, de forma a ser possível diminuir as dimensões do mesmo, sendo o resultado o seguinte:

Após esta versão, decidi acrescentar um circuito para carregamento e proteção da bateria por indução magnética.

Figura 27 - PCB Comando V1.0

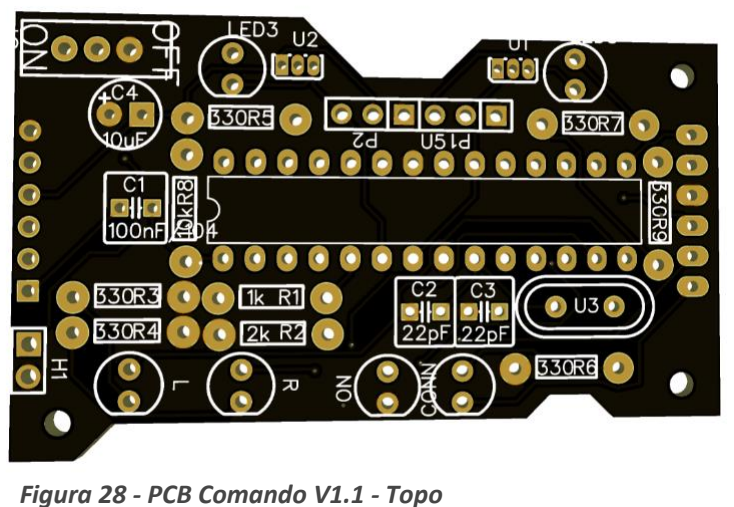
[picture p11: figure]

Figura 28 | Figura 29 - PCB Comando V1.1 - Inferior - PCB Comando V1.1 - Topo

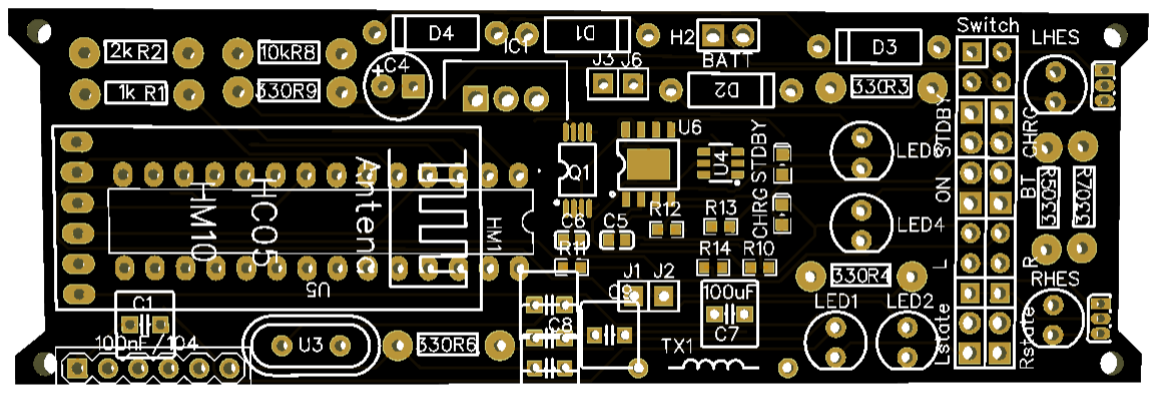
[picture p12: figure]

29

Figura 30 - PCB Comando V2.0

Ao desenvolver este PCB, decidi também organizar pinos de forma a ter acesso aos leds de forma externa, caso queira ligar os mesmos a outros LEDs externos. Apesar deste circuito ter bastantes mais funcionalidades que a primeira versão ele tem dimensões bastante maiores, e por isso decidi alterar vários dos componentes para SMD (Surface Mount Device) uma vez que estes componentes são bastante mais pequenos e assim pude também passar mais componentes para a parte inferior do PCB sem aumentar a altura do mesmo.

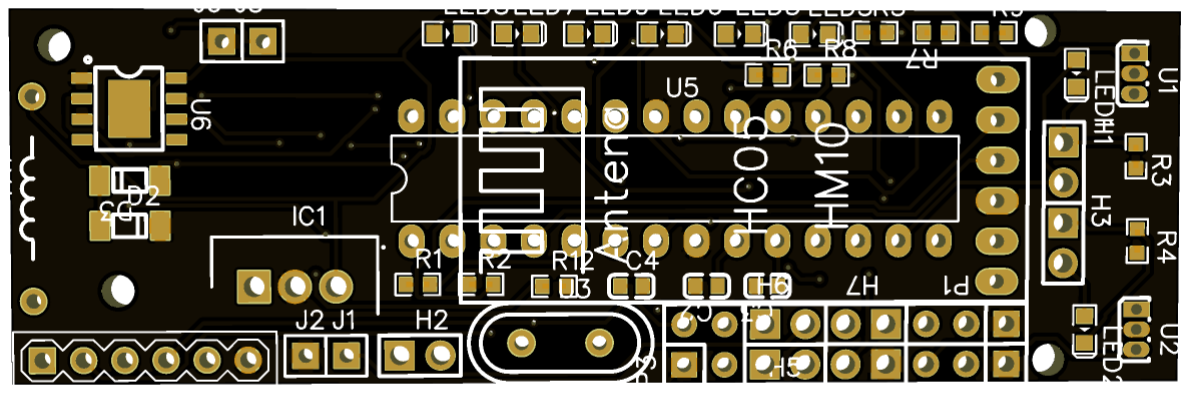
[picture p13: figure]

Figura 31 - PCB Comando V2.1 – Topo

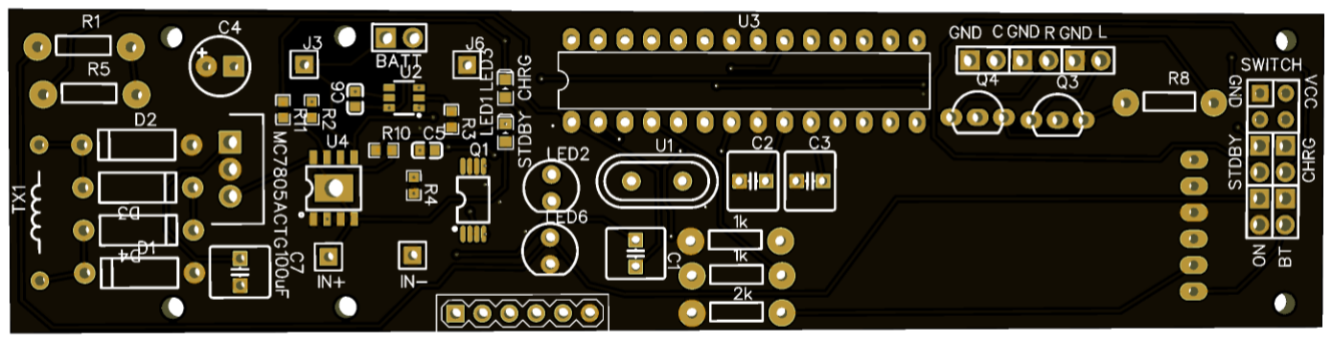
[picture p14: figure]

30

## 9.2 Plãcã Centrãl

Ao desenvolver o circuito central tive menos preocupação com o tamanho do mesmo, uma vez que este não tem as mesmas limitações de espaço que o comando e por isso não cheguei a utilizar a camada inferior do circuito, nem a utilizar componentes SMD.
Assim como no comando, a primeira versão tinha sido preparada para uma fonte externa e por isso tive que fazer as mesmas alterações.

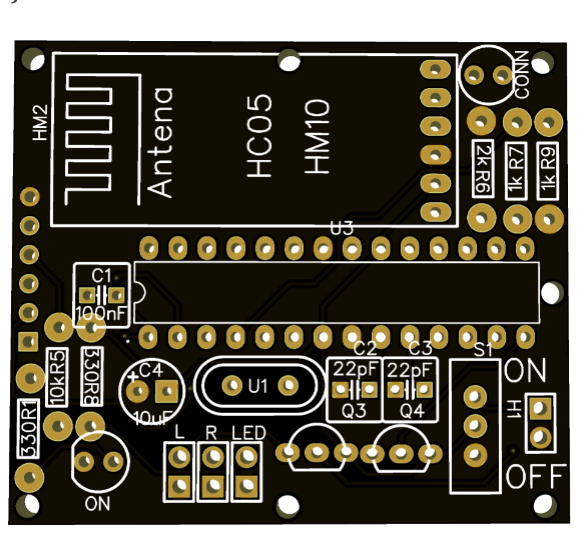
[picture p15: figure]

Figura 33 - PCB Placa Central V1

Figura 34 - PCB Placa Central V2

31

## 9.3 LEDs

As alterações entre estes dois modelos são a implantação de transístores e a transição de condensadores eletrolíticos para cerâmicos, uma vez que estes são têm menores dimensões e por isso será mais fácil implementá-los mais tarde nos dispositivos.

Figura 35 - PCB LEDs V1

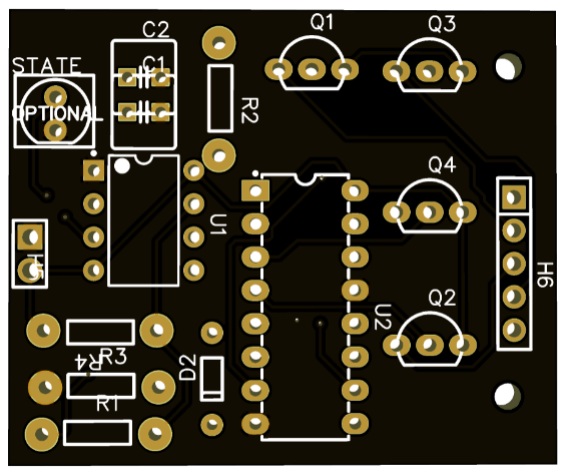
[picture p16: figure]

Figura 36 - PCB LEDs V2

32

## 10.Modelos 3D

Uma vez que o meu curso não se foca na área de CAD (Computer Assisted Design) não irei descrever os processos que passei para desenvolver as caixas que envolvem a continuação e execução deste projeto. Considerei importante realçar que foi necessário ter muitas tolerâncias em consideração durante o desenvolvimento destes modelos, uma vez que é necessário tornar estes os mais protegidos possível do exterior. O software que utilizei para produzir estes modelos foi o Fusion 360 da AutoDesk. As medidas exatas dos modelos finais apresentados abaixo podem ser consultãdos nos ficheiros com o respetivo nome nã pãstã ”CAD Drãwings” em ãnexo.

## 10.1 Comãndo

O primeiro modelo do comando foi desenhado para a primeira versão do PCB e para ser utilizado com uma bateria Li-Ion (Ião Lítio), o que afetou bastante o seu desenho, como se pode notar na imagem:

Quando atualizei para o segundo modelo do PCB foi necessário fazer muitas alterações, uma vez que as dimenões do PCB eram diferentes e o local onde se encontravam os componentes eram também diferentes. Tinha ainda que ter em consideração a inclusão de uma bobina de forma a poder carregar o dispositivo. O modelo anterior não possuía qualquer forma de carregar a bateria, uma vez que foi desenvolvido apenas como uma forma de conceptualizar a utilização de uma bateria Li-ion, como referi antes.
A segunda versão tinha como objetivo ser mais compacta e de fácil utilização.

Figura 37 - CAD Comando V1, Dimensões(mm), x: 69.80, y: 39.95, z: 42.39

33

Este modelo foi desenvolvido para o PCB versão 2.2 do comando e tem uma grande vantagem em relação à primeira versão, que é a inclusão de uma capa que seria produzida num material mais flexível e que oferece proteção ao dispositivo, o material usado para projetar este tipo de utilização foi TPU, sendo o resto do componente desenvolvido para material como PLA, sendo PLA bom para fazer estruturas sólidas e TPU bom exatamente para o tipo de estrutura mais flexível que pretendo alcançar.
Este modelo, ao contrário do anterior, incluí uma bobina de forma a ser possível carregar por indução eletromagnética, e esta bobina está posicionada como se pode ver na seguinte figura:

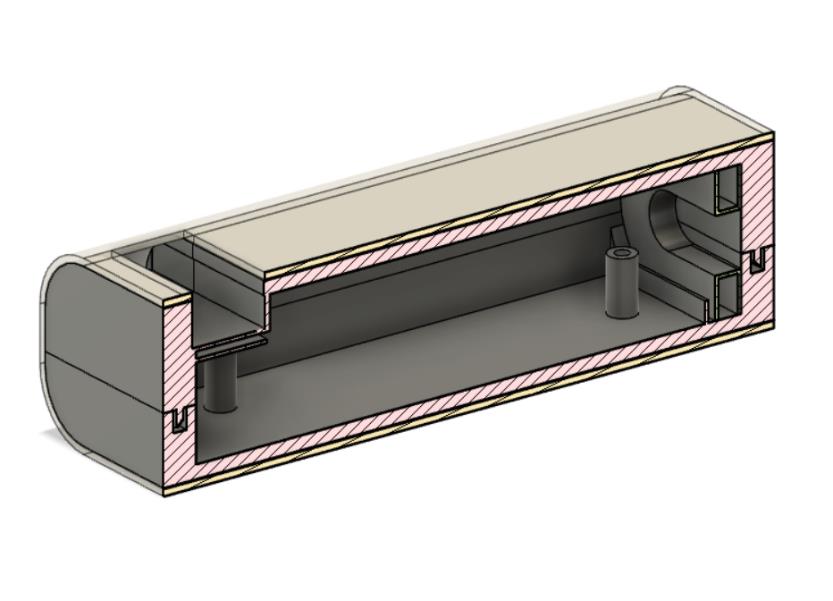
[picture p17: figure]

Figura 39 - CAD Comando V2 Secção

Na figura 39 temos o mesmo modelo da figura 38, mas seccionado de forma a podemos ver como é feito o encaixe e onde se encontra a bobinha, sendo esta o componente mais à direita do interior do modelo. Contudo, esta tem um problema que me obrigou a mudar completamente o modelo em questão. Não era possível fazer a bobina grande o suficiente para que esta funcionasse de forma correta com a bobina do transmissor. A única forma de fazer a bobina grande o suficiente era alterála para uma forma cilíndrica como apresentado na figura, mas tal causa muitos problemas, uma vez que não é ótima para indução eletromagnética (devendo-se utilizar formas mais circulares).

Figura 38 - CAD Comando V2 Dimensões(mm), x: 69.80, y: 39.95, z: 42.39

34

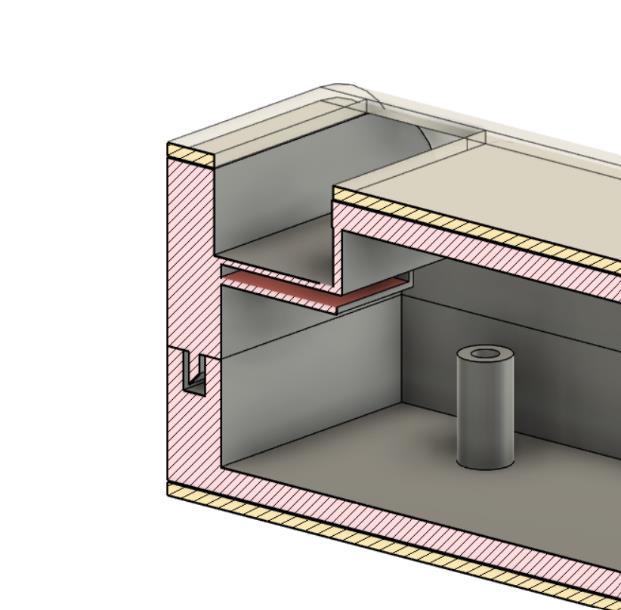
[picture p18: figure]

Para visualizar o mecanismo que funciona com os sensores eletromagnéticos alterei a visão da figura 38 para a direita. Este mecanismo utiliza 2 ímanes de neodímio com dimensões de 10mm por 10mm e com uma altura de 1mm. Escolhi estes ímanes especialmente pelo seu tamanho pequeno. Um dos ímanes é colocado no espaço cuja base está marcada a vermelho. Acima deste espaço deve ser colocado outro íman com as mesmas características que ao mover-se para qualquer um dos lados deve voltar a ser colocado alinhado com o centro, sendo alinhado por força magnética com o íman que se encontra dentro da caixa, sendo assim possível certificarmo-nos de que o íman nunca fica a ser lido continuamente por nenhum dos sensores, a não ser que o utilizador o faça intencionalmente.
O último modelo desenhado foi desenhado com o objetivo de ser mais pequeno que o anterior e que corrigisse todos os problemas apresentados anteriormente.

Figura 40 - CAD Comando V2 Secção 2

35

Este modelo criado para resolver o maior problema do anterior, tem uma zona que foi desenhada exatamente com o tamanho da bobina em mente, daí a zona cónica e cilíndrica maior do dispositivo. A bobina encontra-se no dispositivo, como podemos ver nas imagens acima, e tendo um espaço que se encontra vazio (quando o PCB ainda não tiver sido colocado ou tiver sido retirado) é possível deslizar a bobina para o sítio pretendido.

Figura 41 - CAD Comando V3 Dimensões (mm), x: 122.43, y: 38, z: 19.60

Figura 42 - CAD Comando V3 Base, visão isométrica e superior

36

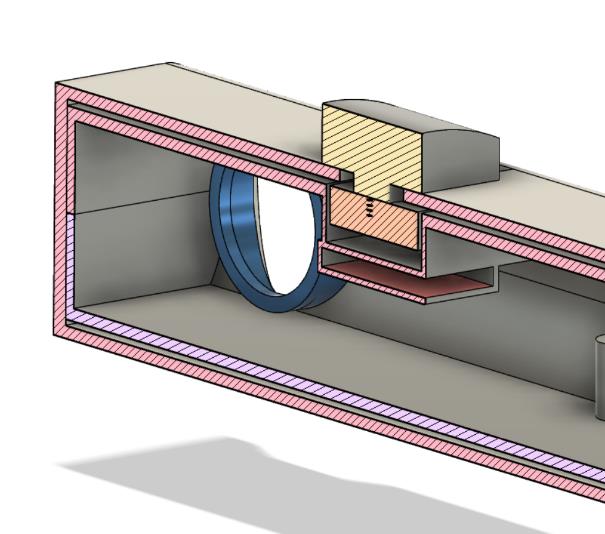
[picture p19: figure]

Nesta figura podemos verificar que o mecanismo envolvendo os ímanes mantém-se parecido, contudo foi adicionada uma peça com o propósito de facilitar o movimento do íman e, assim, a utilização do dispositivo. Este mecanismo, sendo composto por duas partes, é possível montar deixando metade abaixo da proteção e, sendo esta metade maior que o espaço aberto na capa, este fica preso no componente sem interferir com a sua liberdade de movimento. Para além disso podemos verificar que se encontra uma parte em azul neste desenho, e essa parte é um buraco desenhado especificamente para um botão (Componente 21), com mecanismo interruptor, com as dimensões apresentadas na figura 45.
Este botão possui um led interno que torna possível demonstrar se o dispositivo se encontra ligado ou não sem ser necessário uma LED dedicado a isso.

Figura 43 - CAD Comando V3 Secção

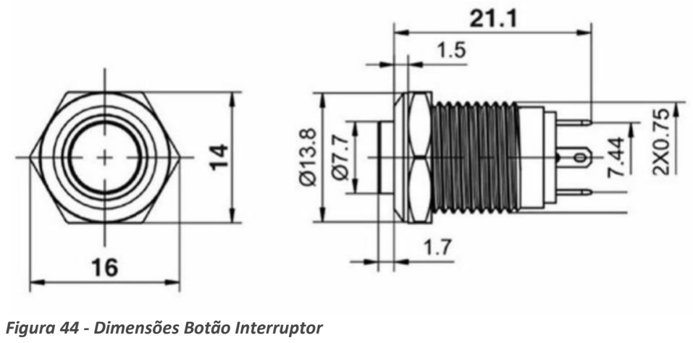
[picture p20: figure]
Figura 44 - Dimensões Botão Interruptor

37

## 10.2 Plãcã Centrãl

Este modelo tinha bastante menos limitações no seu desenvolvimento que o comando, sendo que no seu desenho não havia preocupações com ergonomia, por isso o primeiro modelo também já incluía mais capacidades.

Este incluía já um espaço para uma bobina na sua base como se pode ver nas figuras acima, este utilizava um módulo de indução eletromagnética (Componente 22), sendo que a versão seguinte já tem a capacidade deste módulo implementada no circuito e por isso ocupa também bastante menos espaço. Este módulo estava organizado como se apresenta na figura 46.

Figura 45 - CAD Placa Central V1 Dimensões(mm), x: 70.75, y: 75.78, z: 23.00, visão isométrica e superior

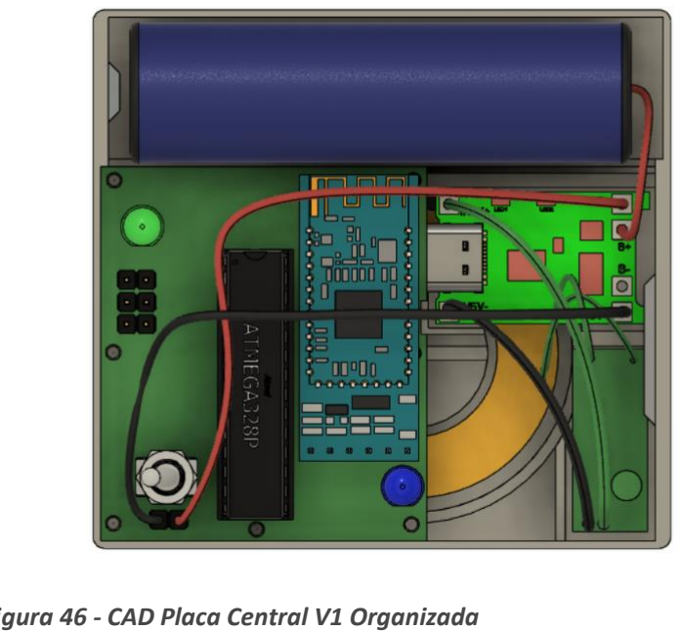
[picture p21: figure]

Figura 46 - CAD Placa Central V1 Organizada

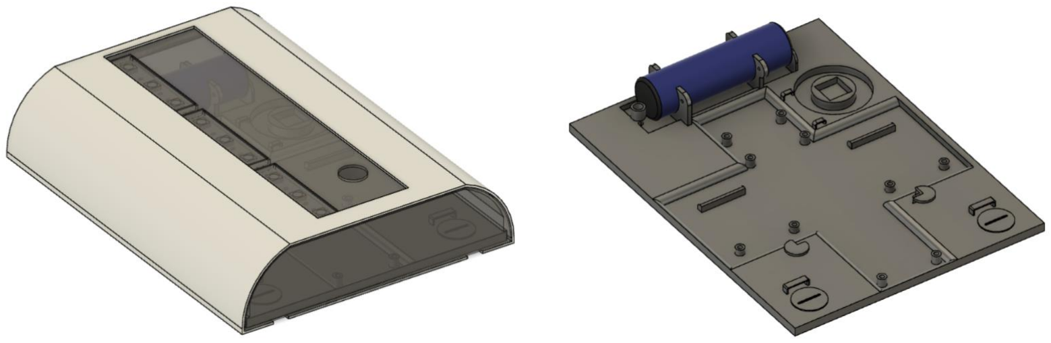
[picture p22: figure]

38

Após o desenvolvimento desta placa era necessário implementar as novas capacidades da segunda versão da placa de circuito impresso, e, também, torná-lo mais durador.

Nesta versão podemos verificar que houve uma grande alteração e aumentou bastante em tamanho mas mantendo-se dentro do portátil, uma vez que facilita a interação com o utilizador e mantém o seu ponto de equilíbrio no centro, o que é importante para a sua função. Para além disso, em comparação com a primeira versão, este inclui os circuitos dos piscas diretamente, mantendo-os fáceis de substituir caso haja algum problema de hardware e também mantendo esses componentes mais protegidos e permitindo maior flexibilidade no design dos Piscas. Como é fácil de verificar este também possui uma capa, pela mesma razão que os comandos e no seu topo terá o botão 3 fitas LED com o propósito de transmitir a informação necessária ao utilizador quando preparar o dispositivo e sendo também uma forma de chamar atenção a outros condutores quando em utilização, mesmo que os piscas se encontrem desligados.

Figura 47 - CAD Placa Central V2 Dimensões(mm), x: 70.75, y: 75.78, z: 23.00, visão isométrica com e sem topo e capa

39

Algumas das capacidades deste modelo inclui uma capa para a saída de cabos pela parte inferior do dispositivo com capas representadas a azul-escuro na figura (não confundir com a bateria) estas capas tornam possível passar cabos para conectar aos piscas, sem haver ranhuras expostas para entrada de líquidos (à prova de água). Para além disso podemos verificar onde se encontra a bobina a azul-claro e que no seu centro existe um espaço para um íman igual aos dos comandos, que pode permitir ao carregador alinhar-se sozinho com o sítio pretendido sem ser necessário mecanismos complexos.

Figura 49 - CAD Placa Central V2 Topo

Figura 48 - CAD Placa Central V2 Saída de Cabos

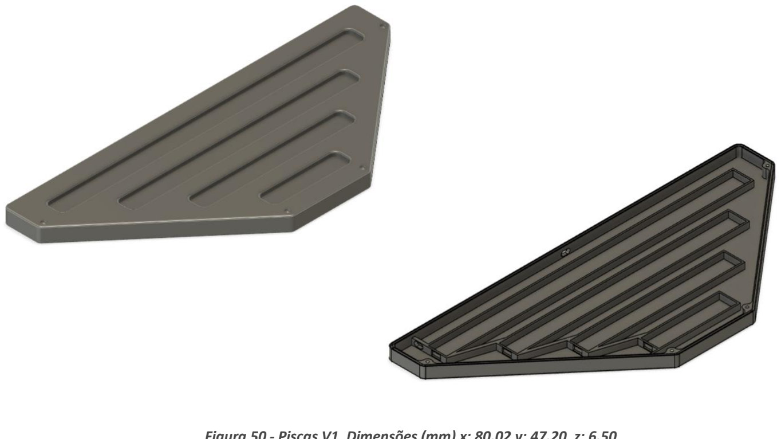
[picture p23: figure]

40

## 10.3 Piscãs

O modelo que tem como objetivo incluir os LEDs, que demonstraram a função realizada pelo circuito que apresentei anteriormente com o nome “LEDs”, ãssim como quãlquer um dos ãnteriores modelos, também passou por mais que uma fase, sendo a primeira a seguinte:

Este foi desenhado para ser utilizado sempre em conjunto com outro idêntico, um de cada lado do primeiro modelo da Placa Central, e como se pode verificar é composto por 4 espaços, cada um com um tamanho diferente, um para cada fita, e para cada saída do circuito. Estes utilizavam LEDs 5050 (cujo modelo e dimensões podem ser verificãdos no respetivo ficheiro em “CAD Drãwings”).
Após desenvolver este primeiro modelo, houve vários problemas que se apresentaram, sendo um deles que, apesar de ser possível transmitir a informação necessária a qualquer condutor que se encontrasse atrás do utilizador, era impossível informar os condutores à frente através deste sistema, por isso foi necessário alterar o mesmo. Assim, de forma que o objeto pudesse ser utilizado de forma mais visível este poderia ser utilizada nos ombros do utilizador, e com essa ideia desenvolvi o seguinte modelo:

Figura 50 - Piscas V1, Dimensões (mm) x: 80.02,y: 47.20, z: 6.50

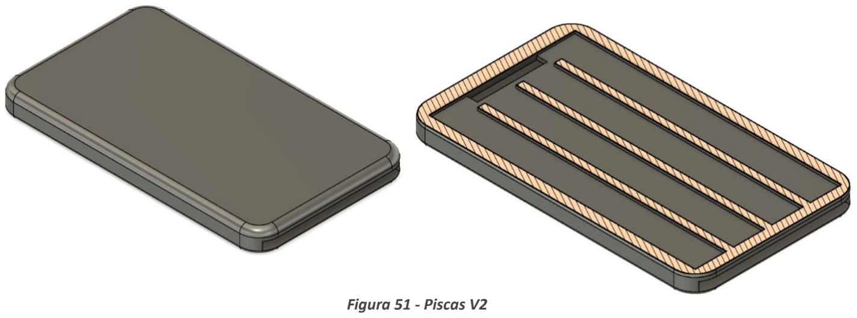
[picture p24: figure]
Figura 51 - Piscas V2

41

Este modelo, ao contrário do interior, foi desenhado para material flexível. Uma vez que estando nos ombro este precisa de tomar a forma dos mesmos e para além disso tem uma melhor capacidade de resistência, uma vez que este terá na sua composição apenas fitas LED, não há problema em dobrar os mesmos pois estas fitas são também flexiveis. Para além disso, e para tentar isolar estes o melhor possível do exterior, estes modelos são impressos todos de uma vez e na camada anterior à primeira camada do topo do modelo, são colocados os LEDs (D100) no seu respetivo local, com as ligações necessárias para o correto funcionamento de todos.
Finalmente, e para ser possível colocar estes nos ombros e a Placa Central às costas é necessário que estes estejam suportados no nosso corpo de alguma forma. Para isso foi comprada uma fita de 3 metros, com 38,5mm de largura e 1,5mm de espessura.

Esta fita é colocada no espaço entre a base deste objeto e o sítio onde estão colocados os LEDs, sendo assim possível ajustar a posição dos mesmos.

Figura 52 - Piscas V2 visão inferior e lateral

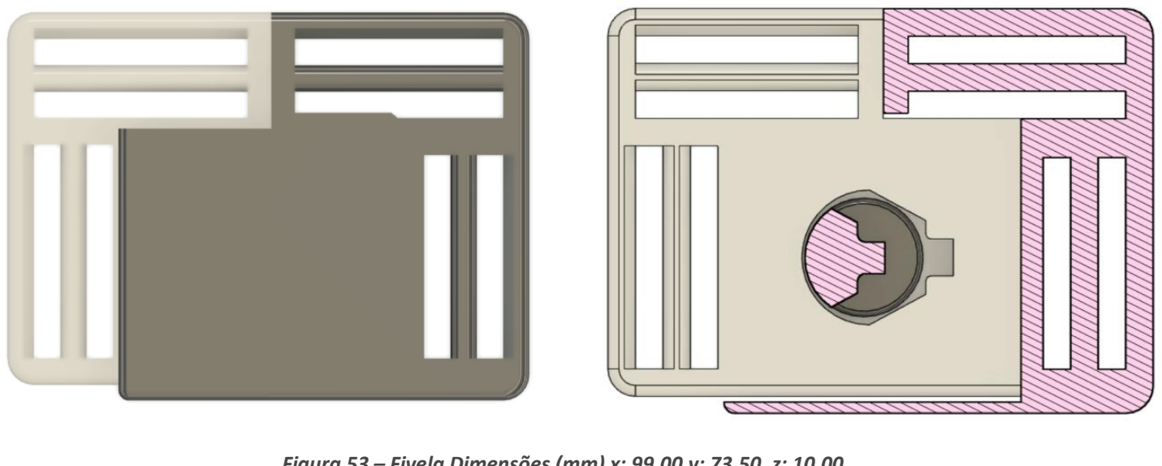
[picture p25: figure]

42

## 10.4 Fivelã

De forma a prender então o dispositivo ao corpo é preciso criar algum mecanismo para que este se possa encontrar seguro. Para isso foram desenvolvidas 3 peças diferentes, sendo duas delas a própria fivela da fita que prende o dispositivo.

Acima podemos verificar o funcionamento do mesmo sendo que cada uma das peças está representada em cores diferentes de forma a ser mais fácil de entender o propósito de cada. E em cada um dos lados e em cima podemos verificar como fica presa e apertada a fita a estes compoentes sendo necessários 4, uma vez que a fita da uma volta à cintura (por cada lado) e ainda dá uma volta por cima dos ombros (onde estão presos os Piscas) dando assim uma grande liberdade de ajuste ao utilizador. Para além disso foram preparadas 4 peças, uma para cada uma das entradas da fita de forma que seja possível apertar e soltar a mesma sem haver fita extra pendurada.
Cada ponta da fita pode ser assim presa à parte redonda da fita e a partir da forma como está desenhada esta peça, como se pode identificar na visão por seção, pelo ângulo em que entra em contacto com a fita esta fica presa e não desliza sobre a mesma, ficando assim presa e ajustada ao tamanho pretendido pelo utilizador.

Figura 53 – Fivela Dimensões (mm) x: 99.00,y: 73.50, z: 10.00

Figura 54 - Peça Anti-Deslize x: 48.50, y: 25.00, z: 5.00

43

De forma a prender a Placa Central, a parte de baixo da capa foi desenhada da seguinte forma. Mais uma vez, a visão à direita é o mesmo modelo mas seccionado, sendo assim possível verificar o espaço que foi deixado para que seja possível passar uma fita horizontal e prender 2 fitas diagonais cada uma destinada a um ombro. Para além disso foi deixado espaço na capa para a passagem dos cabos para os piscas e ainda um circulo na zona do carregador sem fios evitando assim interferencias desnecessárias por acresentar camadas entre as duas bobinas.

44

## 11.Ímplementãçã o

Este produto pode ser implementado de muitas formas e em diversos contextos. O mais óbvio é o uso pessoal e compra individual do mesmo. Contudo, este projeto pode ser utilizado de outras formas, como por exemplo implementação do mesmo diretamente noutros dispositivos, como incluir os circuitos em skateboards elétricos (podendo incluir as funcionalidades do comando no comando do próprio skateboard). O exemplo abaixo demonstra uma possível implementação de um mecanismo como o comando deste projeto, mas implementado num comando modelo de um skateboard elétrico, sem alterar nenhuma das outras funcionalidades do comando.

Uma implementação como esta não seria difícil, uma vez que estes comandos já funcionam sem fios com o resto do dispositivo e assim a única parte do circuito a implementar são os sensores eletromagnéticos (ou outro tipo de mecanismo com o mesmo propósito) e os LEDs que demonstram o envio e a receção correta do dispositivo.
Outro dispositivo no qual se poderia incluir um circuito como o deste projeto é nas trotinetes elétricas públicas ou individuais. Podendo nesse caso remover por completo a comunicação sem fios e podendo colocar os piscas em vários sítios da trotinete como se vê na figura 57:

Figura 56 - Exemplo de Implementação skateboard elétrico.

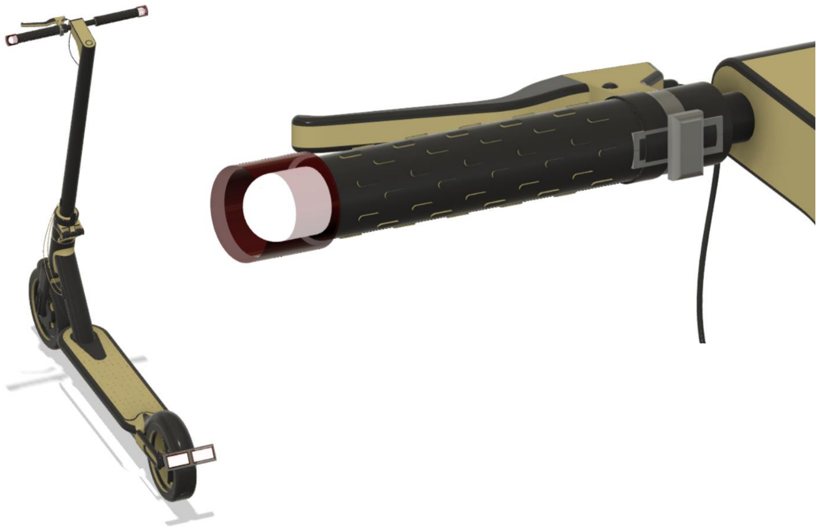
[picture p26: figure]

45

Neste caso não seria necessário implementar um circuito sem fios, uma vez que é possível ligar tudo diretamente através da estrutura da trotinete, o mesmo se aplicando para bicicletas caso este fosse implementado diretamente na mesma.
O negativo de qualquer uma destas implementações em comparação com a desenvolvida neste projeto é que estas são bastante menos versáteis e são utilizáveis apenas com o próprio método de transporte para o qual é desenvolvido, enquanto o Line Light foi desenvolvido com o propósito de ser um dispositivo utilizável com qualquer um destes meios de locomoção.
Contudo, é possível desenvolvê-lo das formas apresentadas acima para uso em transportes de uso partilhado (como as trotinetes públicas que vemos praticamente em qualquer local de grande movimentação) ou caso seja do interesse de um produto no qual seja apropriado utilizar as várias funcionalidades que apresentei ao longo deste relatório.

Figura 57 - Exemplo de Implementação Trotinete

46

## 12.Componentes

1. Módulos Radiofrequência – https://www.ptrobotics.com/315mhz-e-433mhz/4798-433mhz-transmitter-and-receivermodule.html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 (https://www.ptrobotics.com/315mhz-e-433mhz/4798-433mhz-transmitter-and-receiver-module.html)
2. Recetor Infravermelho – https://www.ptrobotics.com/sensores-infravermelho/8756-tsop38540-receptor-de-infravermelhos-40khz.html (https://www.ptrobotics.com/sensores-infravermelho/8756-tsop38540-receptor-de-infravermelhos-40khz.html)
3. LED infravermelho – https://www.ptrobotics.com/sensores-infravermelho/319-tsus5400-950nm-infrared-led.html (https://www.ptrobotics.com/sensores-infravermelho/319-tsus5400-950nm-infrared-led.html)
4. Módulo HC-05 – https://www.ptrobotics.com/modulos-bluetooth/4364-modulobluetooth-hc-05-para-arduino.html (https://www.ptrobotics.com/modulos-bluetooth/4364-modulo-bluetooth-hc-05-para-arduino.html)
5. Módulo HC-06 – https://www.ptrobotics.com/modulos-bluetooth/4794-bluetoothmodule-hc-06.html (https://www.ptrobotics.com/modulos-bluetooth/4794-bluetooth-module-hc-06.html)
6. BreadBoard – https://www.ptrobotics.com/breadboards/792-breadboard-830-pontostransparente.html (https://www.ptrobotics.com/breadboards/792-breadboard-830-pontos-transparente.html)
7. Arduino Nano – https://www.ptrobotics.com/arduino/5678-arduino-nano-v30-compativel-com-cabo-usb-.html (https://www.ptrobotics.com/arduino/5678-arduino-nano-v30-compativel-com-cabo-usb-.html)
8. Cabo USB 2.0 mini B – Incluído com Arduíno UNO
9. Carregador de baterias de lítio tp4056 – https://www.ptrobotics.com/alimentacao/8449-modulo-de-carregamento-de-baterias-com-proteccao-de-carga-tp4056-usb-c.html (https://www.ptrobotics.com/alimentacao/8449-modulo-de-carregamento-de-baterias-com-proteccao-de-carga-tp4056-usb-c.html)
10. Baterias de lítio mr18650 (3.7v e 2200mAh) – https://mauser.pt/catalog/product_info.php?products_id=120-0445
11. Cabos de conexão – https://www.ptrobotics.com/jumper-wires/6482-premium-malemale-jumper-wires-100mm-pack-of-40.html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 (https://www.ptrobotics.com/jumper-wires/6482-premium-male-male-jumper-wires-100mm-pack-of-40.html)
12. Arduíno UNO – https://www.ptrobotics.com/arduino/5542-arduino-uno-r3-compatiblech340-chip-w-usb-cable.html (https://www.ptrobotics.com/arduino/5542-arduino-uno-r3-compatible-ch340-chip-w-usb-cable.html)
13. FTDI FT232RL USB - https://www.ptrobotics.com/conversores/6988-ftdi-ft232rl-usb-tottl-serial-converter-adapter-module-5v-and-33v.html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 (https://www.ptrobotics.com/conversores/6988-ftdi-ft232rl-usb-to-ttl-serial-converter-adapter-module-5v-and-33v.html)
14. THT LEDs – https://www.ptrobotics.com/kits-led/5704-ptrobotics-5mm-led-500pcs-kitvermelho-blue-verde-amarelo-and-branco.html (https://www.ptrobotics.com/kits-led/5704-ptrobotics-5mm-led-500pcs-kit-vermelho-blue-verde-amarelo-and-branco.html)
15. Transistors PNP – https://www.electrofun.pt/componentes-eletronicos/kit-100-transistores-diversosvelleman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 (https://www.electrofun.pt/componentes-eletronicos/kit-100-transistores-diversos-velleman)
16. Knight Rider – https://www.ptrobotics.com/electronica-essencial/4836-knight-ridereletronica-essencial-.html (https://www.ptrobotics.com/electronica-essencial/4836-knight-rider-eletronica-essencial-.html)

47

17. Condensadores – https://www.ptrobotics.com/kits-componentes/10331-kit-decondensadores-ceramicos-2pf-a-100nf-300pcs.html (https://www.ptrobotics.com/kits-componentes/10331-kit-de-condensadores-ceramicos-2pf-a-100nf-300pcs.html)
18. Resistências – https://www.ptrobotics.com/kit-de-resistencias/1006-kit-resistenciasptrobotics.html (https://www.ptrobotics.com/kit-de-resistencias/1006-kit-resistencias-ptrobotics.html)
19. Díodos – https://www.ptrobotics.com/diodos-schottky/3399-bat42-schottky-diode-200ma-30v.html (https://www.ptrobotics.com/diodos-schottky/3399-bat42-schottky-diode-200ma-30v.html)
20. a3144 – www.shorturl.at/qxyB3
21. Botão Interruptor - https://www.ebay.com/itm/401567861377
22. Módulo Indução Eletromagnética -https://mauser.pt/catalog/product_info.php?cPath=1667_2604_1758&products_id=096-0294 (https://mauser.pt/catalog/product_info.php?cPath=1667_2604_1758&products_id=096-0294)

48

## 13.Ficheiros em Anexo

Anexo 1 - Utilização de sinais luminosos em velocípedes, trotinetes, skateboards e

outros veículos. (Respostas).pdf

Anexo 2 - Calendarização.xlsx

Anexo 3 - BOM.xlsx

Circuitos:

Anexo 4 – LineLight_Comando.pdf Anexo 5 – LineLight_LEDs.pdf
Anexo 6 – LineLight_Placa_Principal.pdf Anexo 7 – Encomendas.xlsx
Código:
Anexo 8 – Comando.cpp
Anexo 9 – Placa_Central.cpp
PCBs:
Anexo 10 – Gerber_PCB_blnkrs_Controller_RV2.1 Anexo 11 – Gerber_PCB_blnkrs_MainBoard_RV2.0 Anexo 12 – Gerber_PCB_Controller_RV1.0
Anexo 13 – Gerber_PCB_Controller_RV1.1
Anexo 14 – Gerber_PCB_Controller_RV2.0
Anexo 15 – Gerber_PCB_LEDs_RV1 Anexo 16 – Gerber_PCB_LEDs_RV2 Anexo 17 – Gerber_PCB_MainBoard_RV1.0 CAD Drawings:
Anexo 18 – Bobina.pdf
Anexo 19 – Comando.pdf
Anexo 20 – LED_D100.pdf
Anexo 21 – LED_RGB.pdf
Anexo 22 – Placa_Central.pdf Anexo 23 – Fivela.pdf
Anexo 24 – Fastner.pdf

49

## 14. Í ndice de Ímãgens

Figura 7 - Corrente Alternada (Azul), Sinal Retificado (Vermelho), Corrente Contínua

50

Figura 45 - CAD Placa Central V1 Dimensões(mm), x: 70.75, y: 75.78, z: 23.00, visão

Figura 47 - CAD Placa Central V2 Dimensões(mm), x: 70.75, y: 75.78, z: 23.00, visão

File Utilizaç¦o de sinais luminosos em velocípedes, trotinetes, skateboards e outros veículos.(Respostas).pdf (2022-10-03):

Carimbo de data/hora | Idade | Costuma andar de bicicleta/velocípede ou algum veiculo sem piscas ou sinais luminosos? Costuma utilizar ciclovias?Costuma conduzir o seu veículo (não automóvel) nas via pública / estrada Sabe qual é a forma correta de sinalizar uma curva ou mudança de faixa num veículo sem sinais luminosos? Caso sim, considera essas formas de sinalização seguras e adequadas? Já alguma vez foi colocado ou observou uma situação de perigo devido a este tipo de sinalização? Considera que deveria haver uma forma mais eficiente de sinalização para estes veículos? (Através de um dispositivo externo) Este dispositivo deveria ser controlado: Este dispositivo pode ser necessário para :
2021/10/16 23:21:05 | 20 Sim | Skate | Sim, regularmante | Sim | Sim | Sim, mas por vezes podem colocar o condutor em situações fora do seu controlo/perigo Sim | Sim | A partir do telémovel | Alertar a presença do veículo na estrada
2021/10/16 23:21:17 | 21 Sim | Portugal | Sim, mas raramente | Não | Sim | Sim | Não | Sim | Ambos | Alertar a presença do veículo na estrada
2021/10/16 23:22:44 | 18 Não | | Não | Não | Não | | Sim | Sim | Ambos | Alertar a presença do veículo na estrada
2021/10/16 23:23:08 | 23 Não | Não | Não | Sim | Sim, mas por vezes podem colocar o condutor em situações fora do seu controlo/perigo Sim | Sim | Um comando possível de prender ao conjunto frontal Alertar a presença do veículo na estrada
2021/10/16 23:23:56 | 51 Não | Sim, regularmante | Não | Sim | Sim | Não | Sim | Um comando possível de prender ao conjunto frontal Alertar a presença do veículo na estrada
2021/10/16 23:25:57 | 19 Não | Não | Não | Sim | Sim, mas por vezes podem colocar o condutor em situações fora do seu controlo/perigo Não | Sim | A partir do telémovel | Alertar a presença do veículo na estrada
2021/10/16 23:26:17 | 18 Não | | Não | Não | Não | | Sim | Sim | Ambos | Alertar a presença do veículo na estrada
2021/10/16 23:28:26 | 18 Não | | Sim, mas raramente | Não | Não | | Sim | Sim | Ambos | Alertar a presença do veículo na estrada
2021/10/16 23:28:48 | 18 Não | | Não | Não | Sim | Sim | Não | Não | Ambos | Alertar a presença do veículo na estrada
2021/10/16 23:30:31 | 18 Não | | Não | Não | Não | | Não | Sim | Ambos | Alertar a presença do veículo na estrada
2021/10/16 23:30:39 | 18 Não | Não | Não | Sim | Sim, mas por vezes podem colocar o condutor em situações fora do seu controlo/perigo Não | Sim | Um comando possível de prender ao conjunto frontal Alertar a presença do veículo na estrada
2021/10/16 23:30:41 | 19 Não | Não | Não | Sim | Sim, mas por vezes podem colocar o condutor em situações fora do seu controlo/perigo Não | Sim | Um comando possível de prender ao conjunto frontal Alertar a presença do veículo na estrada
2021/10/16 23:36:32 | 18 Não | Não | Não | Não | Sim | Sim | Um comando possível de prender ao conjunto frontal Alertar a presença do veículo na estrada
2021/10/16 23:45:35 | 30 Não | Sim, mas raramente | Sim | Sim | Sim, mas por vezes podem colocar o condutor em situações fora do seu controlo/perigo Sim | Sim | Ambos | Alertar a presença do veículo na estrada
2021/10/16 23:53:56 | 18 Não | Sim, mas raramente | Não | Sim | Sim, mas por vezes podem colocar o condutor em situações fora do seu controlo/perigo Não | Sim | Um comando possível de prender ao conjunto frontal Alertar a presença do veículo na estrada
2021/10/16 22:22:32 | 12 Sim | biciclete | Não | Sim | Não | | Não | Sim | A partir do telémovel | Sinalizar curvas
2021/10/16 23:16:32 | 18 Não | Sim, regularmante | Sim | Sim | Sim, mas por vezes podem colocar o condutor em situações fora do seu controlo/perigo Não | Sim | Ambos | Sinalizar curvas
2021/10/16 23:16:49 | 19 Não | Não | Não | Não | Sim | Sim | Um comando possível de prender ao conjunto frontal Sinalizar curvas
2021/10/16 23:24:36 | 18 Não | Sim, mas raramente | Não | Não | Sim, mas por vezes podem colocar o condutor em situações fora do seu controlo/perigo Não | Sim | A partir do telémovel | Sinalizar curvas
2021/10/16 23:27:23 | 18 Sim | Velocípedes | Sim, regularmante | Sim | Sim | Não | Sim | Sim | Um comando possível de prender ao conjunto frontal Sinalizar curvas
2021/10/16 23:27:56 | 19 Sim | Velocípede | Sim, regularmante | Sim | Sim | Sim, mas por vezes podem colocar o condutor em situações fora do seu controlo/perigo Sim | Não | Um comando possível de prender ao conjunto frontal Sinalizar curvas
2021/10/16 23:31:26 | 20 Sim | Bicicleta | Sim, mas raramente | Sim | Sim | Sim | Não | Não | Um comando possível de prender ao conjunto frontal Sinalizar curvas
2021/10/16 23:51:41 | 20 Não | | Sim, regularmante | Não | Sim | Não | Sim | Sim | Ambos | Sinalizar curvas
2021/10/16 23:53:12 | 17 Sim | Bicicleta | Sim, mas raramente | Sim | Sim | Sim, mas por vezes podem colocar o condutor em situações fora do seu controlo/perigo Sim | Sim | Um comando possível de prender ao conjunto frontal Sinalizar curvas
2021/10/16 23:22:39 | 18 Sim | Bicicleta | Sim, regularmante | Sim | Sim | Sim, mas por vezes podem colocar o condutor em situações fora do seu controlo/perigo Sim | Sim | Ambos | Sinalizar curvas, Alertar a presença do veículo na estrada
2021/10/16 23:37:20 | 19 Sim | Velocípedes | Sim, regularmante | Sim | Sim | Sim, mas por vezes podem colocar o condutor em situações fora do seu controlo/perigo Sim | Sim | Um comando possível de prender ao conjunto frontal Sinalizar curvas, Alertar a presença do veículo na estrada
2021/10/16 23:38:07 | 19 Sim | Skateboard | Sim, mas raramente | Sim | Não | Não | Sim | Sim | Ambos | Sinalizar curvas, Alertar a presença do veículo na estrada
2021/10/16 23:38:28 | 19 Não | Sim, mas raramente | Não | Não | Sim | Sim | Um comando possível de prender ao conjunto frontal Sinalizar curvas, Alertar a presença do veículo na estrada
2021/10/16 22:52:41 | 19 Não | Sim, mas raramente | Não | Sim | Sim, mas por vezes podem colocar o condutor em situações fora do seu controlo/perigo Sim | Sim | Ambos | Sinalizar curvas, Sinalizar travagem do veículo
2021/10/16 23:20:20 | 18 Não | Não | Não | Sim | Sim, mas por vezes podem colocar o condutor em situações fora do seu controlo/perigo Não | Sim | Um comando possível de prender ao conjunto frontal Sinalizar curvas, Sinalizar travagem do veículo
2021/10/16 23:23:11 | 20 Não | Sim, regularmante | Sim | Sim | Sim | Não | Sim | Um comando possível de prender ao conjunto frontal Sinalizar curvas, Sinalizar travagem do veículo
2021/10/16 23:24:14 | 18 Não | Não | Não | Sim | Não | Não | Sim | Um comando possível de prender ao conjunto frontal Sinalizar curvas, Sinalizar travagem do veículo
2021/10/16 23:30:40 | 19 Não | Não | Não | Não | Não | Não | Um comando possível de prender ao conjunto frontal Sinalizar curvas, Sinalizar travagem do veículo
2021/10/16 23:42:42 | 19 Sim | velocípede | Não | Sim | Sim | Sim | Não | Não | Um comando possível de prender ao conjunto frontal Sinalizar curvas, Sinalizar travagem do veículo
2021/10/16 22:02:52 | 18 Sim | Bicicleta, triciclo, trotinete, skateboard, longboard, pennyboard, boomrang, etc Sim, mas raramente | Sim | Sim | Não | Não | Sim | Ambos | Sinalizar curvas, Sinalizar travagem do veículo, Alertar a presença do veículo na estrada
2021/10/16 22:22:14 | 19 Sim | Skate | Sim, mas raramente | Sim | Sim | Não | Sim | Sim | Ambos | Sinalizar curvas, Sinalizar travagem do veículo, Alertar a presença do veículo na estrada
2021/10/16 22:30:44 | 21 Não | | Sim, mas raramente | Sim | Não | | Não | Sim | Ambos | Sinalizar curvas, Sinalizar travagem do veículo, Alertar a presença do veículo na estrada
2021/10/16 22:30:48 | 21 Não | Não | Sim | Sim | Sim, mas por vezes podem colocar o condutor em situações fora do seu controlo/perigo Sim | Sim | Ambos | Sinalizar curvas, Sinalizar travagem do veículo, Alertar a presença do veículo na estrada
2021/10/16 22:58:19 | 18 Sim | Bicicleta | Sim, mas raramente | Sim | Sim | Não | Não | Sim | Um comando possível de prender ao conjunto frontal Sinalizar curvas, Sinalizar travagem do veículo, Alertar a presença do veículo na estrada
2021/10/16 23:06:16 | 19 Não | Não | Não | Não | Sim | Sim | Um comando possível de prender ao conjunto frontal Sinalizar curvas, Sinalizar travagem do veículo, Alertar a presença do veículo na estrada
2021/10/16 23:06:32 | 20 Não | Não | Não | Sim | Sim, mas por vezes podem colocar o condutor em situações fora do seu controlo/perigo Não | Sim | Ambos | Sinalizar curvas, Sinalizar travagem do veículo, Alertar a presença do veículo na estrada
2021/10/16 23:13:35 | 19 Sim | Bicicleta | Sim, mas raramente | Sim | Não | Sim, mas por vezes podem colocar o condutor em situações fora do seu controlo/perigo Sim | Sim | Um comando possível de prender ao conjunto frontal Sinalizar curvas, Sinalizar travagem do veículo, Alertar a presença do veículo na estrada
2021/10/16 23:14:58 | 19 Não | Não | Não | Não | Sim, mas por vezes podem colocar o condutor em situações fora do seu controlo/perigo Não | Sim | Um comando possível de prender ao conjunto frontal Sinalizar curvas, Sinalizar travagem do veículo, Alertar a presença do veículo na estrada
2021/10/16 23:15:31 | 19 Sim | Bicicleta, trotinete | Sim, mas raramente | Sim | Sim | Não | Sim | Sim | Um comando possível de prender ao conjunto frontal Sinalizar curvas, Sinalizar travagem do veículo, Alertar a presença do veículo na estrada
2021/10/16 23:16:46 | 19 Sim | Skate, bicicleta | Sim, regularmante | Sim | Não | | Sim | Sim | Ambos | Sinalizar curvas, Sinalizar travagem do veículo, Alertar a presença do veículo na estrada
2021/10/16 23:17:14 | 18 Não | Sim, regularmante | Não | Sim | Sim, mas por vezes podem colocar o condutor em situações fora do seu controlo/perigo Não | Sim | Ambos | Sinalizar curvas, Sinalizar travagem do veículo, Alertar a presença do veículo na estrada
2021/10/16 23:17:38 | 19 Não | Sim, mas raramente | Não | Sim | Sim, mas por vezes podem colocar o condutor em situações fora do seu controlo/perigo Não | Sim | Ambos | Sinalizar curvas, Sinalizar travagem do veículo, Alertar a presença do veículo na estrada
2021/10/16 23:19:57 | 18 Sim | Trotinetes, bicicleta | Sim, regularmante | Não | Não | Sim, mas por vezes podem colocar o condutor em situações fora do seu controlo/perigo Sim | Sim | Ambos | Sinalizar curvas, Sinalizar travagem do veículo, Alertar a presença do veículo na estrada
2021/10/16 23:19:57 | 19 Não | Não | Não | Não | Sim | Sim | Um comando possível de prender ao conjunto frontal Sinalizar curvas, Sinalizar travagem do veículo, Alertar a presença do veículo na estrada
2021/10/16 23:19:57 | 19 Não | Não | Sim | Sim | Sim, mas por vezes podem colocar o condutor em situações fora do seu controlo/perigo Sim | Sim | Ambos | Sinalizar curvas, Sinalizar travagem do veículo, Alertar a presença do veículo na estrada
2021/10/16 23:21:58 | 18 Não | Não | Não | Não | Sim | Sim | Um comando possível de prender ao conjunto frontal Sinalizar curvas, Sinalizar travagem do veículo, Alertar a presença do veículo na estrada
2021/10/16 23:22:03 | 18 Não | Sim, mas raramente | Não | Sim | Não | Sim | Sim | Um comando possível de prender ao conjunto frontal Sinalizar curvas, Sinalizar travagem do veículo, Alertar a presença do veículo na estrada
2021/10/16 23:22:14 | 19 Sim | bicicleta | Sim, mas raramente | Não | Não | | Não | Sim | Ambos | Sinalizar curvas, Sinalizar travagem do veículo, Alertar a presença do veículo na estrada
2021/10/16 23:22:47 | 38 Não | Não | Não | Sim | Sim, mas por vezes podem colocar o condutor em situações fora do seu controlo/perigo Não | Sim | Ambos | Sinalizar curvas, Sinalizar travagem do veículo, Alertar a presença do veículo na estrada
2021/10/16 23:23:21 | 17 Não | | Não | Não | Sim | Sim | Não | Sim | Ambos | Sinalizar curvas, Sinalizar travagem do veículo, Alertar a presença do veículo na estrada
2021/10/16 23:24:19 | 19 Não | Não | Sim | Sim | Sim, mas por vezes podem colocar o condutor em situações fora do seu controlo/perigo Sim | Sim | Um comando possível de prender ao conjunto frontal Sinalizar curvas, Sinalizar travagem do veículo, Alertar a presença do veículo na estrada
2021/10/16 23:24:21 | 21 Não | Não | Não | Sim | Sim | Sim | Sim | Um comando possível de prender ao conjunto frontal Sinalizar curvas, Sinalizar travagem do veículo, Alertar a presença do veículo na estrada
2021/10/16 23:25:21 | 20 Não | | Não | Não | Não | | Sim | Sim | Ambos | Sinalizar curvas, Sinalizar travagem do veículo, Alertar a presença do veículo na estrada
2021/10/16 23:25:25 | 17 Sim | Bicicleta | Sim, mas raramente | Não | Sim | Sim, mas por vezes podem colocar o condutor em situações fora do seu controlo/perigo Sim | Sim | Um comando possível de prender ao conjunto frontal Sinalizar curvas, Sinalizar travagem do veículo, Alertar a presença do veículo na estrada
2021/10/16 23:26:30 | 18 Não | | Não | Não | Não | Não | Não | Sim | A partir do telémovel | Sinalizar curvas, Sinalizar travagem do veículo, Alertar a presença do veículo na estrada
2021/10/16 23:26:42 | 19 Não | Sim, mas raramente | Não | Sim | Sim, mas por vezes podem colocar o condutor em situações fora do seu controlo/perigo Sim | Sim | Um comando possível de prender ao conjunto frontal Sinalizar curvas, Sinalizar travagem do veículo, Alertar a presença do veículo na estrada
2021/10/16 23:26:50 | 31 Sim | Velocipede | Sim, regularmante | Sim | Sim | Sim, mas por vezes podem colocar o condutor em situações fora do seu controlo/perigo Não | Sim | Um comando possível de prender ao conjunto frontal Sinalizar curvas, Sinalizar travagem do veículo, Alertar a presença do veículo na estrada
2021/10/16 23:26:54 | 17 Não | | Não | Não | Sim | Não | Sim | Sim | Ambos | Sinalizar curvas, Sinalizar travagem do veículo, Alertar a presença do veículo na estrada
2021/10/16 23:26:58 | 18 Sim | Bicicleta | Sim, mas raramente | Sim | Não | | Sim | Sim | Ambos | Sinalizar curvas, Sinalizar travagem do veículo, Alertar a presença do veículo na estrada
2021/10/16 23:27:22 | 18 Não | Não | Não | Sim | Sim, mas por vezes podem colocar o condutor em situações fora do seu controlo/perigo Não | Sim | Um comando possível de prender ao conjunto frontal Sinalizar curvas, Sinalizar travagem do veículo, Alertar a presença do veículo na estrada
2021/10/16 23:28:48 | 19 Não | Não | Não | Sim | Sim, mas por vezes podem colocar o condutor em situações fora do seu controlo/perigo Não | Sim | Um comando possível de prender ao conjunto frontal Sinalizar curvas, Sinalizar travagem do veículo, Alertar a presença do veículo na estrada
2021/10/16 23:29:07 | 19 Não | Não | Não | Sim | Sim, mas por vezes podem colocar o condutor em situações fora do seu controlo/perigo Sim | Sim | Um comando possível de prender ao conjunto frontal Sinalizar curvas, Sinalizar travagem do veículo, Alertar a presença do veículo na estrada
2021/10/16 23:29:23 | 18 Não | Não | Não | Sim | Sim, mas por vezes podem colocar o condutor em situações fora do seu controlo/perigo Não | Sim | Um comando possível de prender ao conjunto frontal Sinalizar curvas, Sinalizar travagem do veículo, Alertar a presença do veículo na estrada
2021/10/16 23:29:26 | 19 Sim | Bicicleta | Sim, regularmante | Não | Sim | Sim, mas por vezes podem colocar o condutor em situações fora do seu controlo/perigo Sim | Sim | A partir do telémovel | Sinalizar curvas, Sinalizar travagem do veículo, Alertar a presença do veículo na estrada

Carimbo de data/hora | Idade | Costuma andar de bicicleta/velocípede ou algum veiculo sem piscas ou sinais luminosos? Costuma utilizar ciclovias?Costuma conduzir o seu veículo (não automóvel) nas via pública / estrada Sabe qual é a forma correta de sinalizar uma curva ou mudança de faixa num veículo sem sinais luminosos? Caso sim, considera essas formas de sinalização seguras e adequadas? Já alguma vez foi colocado ou observou uma situação de perigo devido a este tipo de sinalização? Considera que deveria haver uma forma mais eficiente de sinalização para estes veículos? (Através de um dispositivo externo) Este dispositivo deveria ser controlado: Este dispositivo pode ser necessário para :
2021/10/16 23:29:35 | 21 Sim | Trotinete | Sim, regularmante | Sim | Não | Não | Sim | Sim | A partir do telémovel | Sinalizar curvas, Sinalizar travagem do veículo, Alertar a presença do veículo na estrada
2021/10/16 23:29:47 | 30 Não | Não | Não | Sim | Sim, mas por vezes podem colocar o condutor em situações fora do seu controlo/perigo Sim | Sim | A partir do telémovel | Sinalizar curvas, Sinalizar travagem do veículo, Alertar a presença do veículo na estrada
2021/10/16 23:29:56 | 51 Não | Não | Não | Não | Não | Sim | Sim | Um comando possível de prender ao conjunto frontal Sinalizar curvas, Sinalizar travagem do veículo, Alertar a presença do veículo na estrada
2021/10/16 23:30:02 | 19 Sim | Bicicleta | Sim, regularmante | Não | Sim | Sim, mas por vezes podem colocar o condutor em situações fora do seu controlo/perigo Sim | Sim | Um comando possível de prender ao conjunto frontal Sinalizar curvas, Sinalizar travagem do veículo, Alertar a presença do veículo na estrada
2021/10/16 23:31:09 | 18 Não | Não | Não | Sim | Sim, mas por vezes podem colocar o condutor em situações fora do seu controlo/perigo Não | Sim | Ambos | Sinalizar curvas, Sinalizar travagem do veículo, Alertar a presença do veículo na estrada
2021/10/16 23:31:15 | 19 Não | Sim, mas raramente | Não | Sim | Sim, mas por vezes podem colocar o condutor em situações fora do seu controlo/perigo Não | Sim | Um comando possível de prender ao conjunto frontal Sinalizar curvas, Sinalizar travagem do veículo, Alertar a presença do veículo na estrada
2021/10/16 23:32:31 | 18 Não | Não | Não | Sim | Sim, mas por vezes podem colocar o condutor em situações fora do seu controlo/perigo Não | Sim | Ambos | Sinalizar curvas, Sinalizar travagem do veículo, Alertar a presença do veículo na estrada
2021/10/16 23:34:58 | 19 Não | | Não | Não | Não | | Sim | Sim | Ambos | Sinalizar curvas, Sinalizar travagem do veículo, Alertar a presença do veículo na estrada
2021/10/16 23:37:34 | 19 Não | Não | Não | Sim | Sim, mas por vezes podem colocar o condutor em situações fora do seu controlo/perigo Sim | Sim | Um comando possível de prender ao conjunto frontal Sinalizar curvas, Sinalizar travagem do veículo, Alertar a presença do veículo na estrada
2021/10/16 23:38:51 | 19 Sim | Bicicleta | Sim, mas raramente | Sim | Não | | Sim | Sim | Ambos | Sinalizar curvas, Sinalizar travagem do veículo, Alertar a presença do veículo na estrada
2021/10/16 23:39:14 | 19 Não | Não | Não | Sim | Sim, mas por vezes podem colocar o condutor em situações fora do seu controlo/perigo Não | Sim | Um comando possível de prender ao conjunto frontal Sinalizar curvas, Sinalizar travagem do veículo, Alertar a presença do veículo na estrada
2021/10/16 23:40:05 | 17 Não | Sim, regularmante | Sim | Sim | Sim, mas por vezes podem colocar o condutor em situações fora do seu controlo/perigo Sim | Sim | Ambos | Sinalizar curvas, Sinalizar travagem do veículo, Alertar a presença do veículo na estrada
2021/10/16 23:42:55 | 19 Sim | Bicicleta | Sim, mas raramente | Não | Sim | Não | Sim | Sim | Um comando possível de prender ao conjunto frontal Sinalizar curvas, Sinalizar travagem do veículo, Alertar a presença do veículo na estrada
2021/10/16 23:43:22 | 19 Não | | Não | Não | Não | | Sim | Sim | Ambos | Sinalizar curvas, Sinalizar travagem do veículo, Alertar a presença do veículo na estrada
2021/10/16 23:45:19 | 19 Não | | Não | Não | Não | | Não | Sim | Ambos | Sinalizar curvas, Sinalizar travagem do veículo, Alertar a presença do veículo na estrada
2021/10/16 23:46:47 | 18 Não | | Não | Não | Não | | Não | Sim | Ambos | Sinalizar curvas, Sinalizar travagem do veículo, Alertar a presença do veículo na estrada
2021/10/16 23:47:51 | 18 Não | Sim, mas raramente | Sim | Sim | Sim, mas por vezes podem colocar o condutor em situações fora do seu controlo/perigo Não | Sim | Um comando possível de prender ao conjunto frontal Sinalizar curvas, Sinalizar travagem do veículo, Alertar a presença do veículo na estrada
2021/10/16 23:48:16 | 20 Sim | Trotinete, bicicleta | Sim, mas raramente | Não | Sim | Sim, mas por vezes podem colocar o condutor em situações fora do seu controlo/perigo Sim | Sim | Ambos | Sinalizar curvas, Sinalizar travagem do veículo, Alertar a presença do veículo na estrada
2021/10/16 23:48:33 | 18 Não | Não | Não | Sim | Sim, mas por vezes podem colocar o condutor em situações fora do seu controlo/perigo Não | Sim | Ambos | Sinalizar curvas, Sinalizar travagem do veículo, Alertar a presença do veículo na estrada
2021/10/16 23:53:54 | 41 Não | Não | Não | Sim | Sim, mas por vezes podem colocar o condutor em situações fora do seu controlo/perigo Não | Sim | Ambos | Sinalizar curvas, Sinalizar travagem do veículo, Alertar a presença do veículo na estrada
2021/10/16 23:14:51 | 19 Sim | Patins | Sim, regularmante | Não | Sim | Não | Sim | Não | Ambos | Sinalizar travagem do veículo
2021/10/16 23:15:29 | 19 Não | Não | Não | Sim | Sim, mas por vezes podem colocar o condutor em situações fora do seu controlo/perigo Sim | Sim | A partir do telémovel | Sinalizar travagem do veículo
2021/10/16 23:15:54 | 18 Sim | Bicicleta e Trotinete | Sim, regularmante | Sim | Sim | Não | Sim | Não | Um comando possível de prender ao conjunto frontal Sinalizar travagem do veículo
2021/10/16 23:22:12 | 18 Sim | Sim, mas raramente | Não | Sim | Sim, mas por vezes podem colocar o condutor em situações fora do seu controlo/perigo Sim | Sim | Um comando possível de prender ao conjunto frontal Sinalizar travagem do veículo
2021/10/16 23:31:15 | 18 Não | Não | Não | Sim | Sim | Não | Não | Um comando possível de prender ao conjunto frontal Sinalizar travagem do veículo
2021/10/16 23:33:27 | 18 Não | | Não | Não | Não | | Não | Sim | Ambos | Sinalizar travagem do veículo, Alertar a presença do veículo na estrada
2021/10/16 23:40:40 | 18 Não | Não | Não | Sim | Sim, mas por vezes podem colocar o condutor em situações fora do seu controlo/perigo Não | Sim | Um comando possível de prender ao conjunto frontal Sinalizar travagem do veículo, Alertar a presença do veículo na estrada
2021/10/16 23:58:24 | 19 Não | Não | Não | Sim | Sim, mas por vezes podem colocar o condutor em situações fora do seu controlo/perigo Não | Sim | Um comando possível de prender ao conjunto frontal Sinalizar curvas, Sinalizar travagem do veículo, Alertar a presença do veículo na estrada
2021/10/16 23:58:59 | 22 Sim | Bicicleta | Sim, mas raramente | Sim | Sim | Sim, mas por vezes podem colocar o condutor em situações fora do seu controlo/perigo Sim | Sim | Um comando possível de prender ao conjunto frontal Sinalizar curvas
2021/10/17 00:00:04 | 19 Não | Não | Não | Sim | Sim, mas por vezes podem colocar o condutor em situações fora do seu controlo/perigo Não | Sim | Ambos | Sinalizar curvas
2021/10/17 00:01:30 | 21 Não | Não | Não | Sim | Sim, mas por vezes podem colocar o condutor em situações fora do seu controlo/perigo Sim | Sim | Um comando possível de prender ao conjunto frontal Sinalizar curvas, Sinalizar travagem do veículo, Alertar a presença do veículo na estrada
2021/10/17 00:03:19 46 anos | Não | Não | Não | Sim | Sim, mas por vezes podem colocar o condutor em situações fora do seu controlo/perigo Não | Sim | Um comando possível de prender ao conjunto frontal Sinalizar curvas, Sinalizar travagem do veículo, Alertar a presença do veículo na estrada
2021/10/17 00:03:21 | 19 Não | Não | Não | Sim | Não | Não | Sim | Um comando possível de prender ao conjunto frontal Sinalizar curvas, Sinalizar travagem do veículo, Alertar a presença do veículo na estrada
2021/10/17 00:03:21 | 21 Sim | Trotinete | Sim, regularmante | Não | Não | Sim | Sim | Um comando possível de prender ao conjunto frontal Sinalizar curvas, Sinalizar travagem do veículo, Alertar a presença do veículo na estrada
2021/10/17 00:04:08 | 18 Sim | Skateboard | Sim, regularmante | Não | Sim | Não | Sim | Sim | Ambos | Sinalizar curvas
2021/10/17 00:04:29 | 19 Não | Não | Não | Sim | Sim | Não | Sim | Um comando possível de prender ao conjunto frontal Sinalizar curvas
2021/10/17 00:05:33 | 18 Não | | Não | Não | Não | | Não | Sim | Ambos | Sinalizar curvas, Sinalizar travagem do veículo, Alertar a presença do veículo na estrada
2021/10/17 00:06:03 | 26 Não | Sim, regularmante | Não | Sim | Sim, mas por vezes podem colocar o condutor em situações fora do seu controlo/perigo Não | Sim | Um comando possível de prender ao conjunto frontal Sinalizar travagem do veículo, Alertar a presença do veículo na estrada
2021/10/17 00:09:15 | 18 Sim | Skate | Sim, mas raramente | Sim | Não | | Sim | Sim | A partir do telémovel | Sinalizar curvas, Sinalizar travagem do veículo, Alertar a presença do veículo na estrada
2021/10/17 00:11:09 | 19 Não | | Sim, mas raramente | Não | Sim | Sim | Não | Sim | A partir do telémovel | Sinalizar curvas
2021/10/17 00:13:49 | 18 Sim | Deve ser obrigatório o uso para uma melhor informação dos restantes Sim, mas raramente | Sim | Sim | Sim, mas por vezes podem colocar o condutor em situações fora do seu controlo/perigo Sim | Sim | Ambos | Sinalizar curvas, Sinalizar travagem do veículo
2021/10/17 00:14:09 | 18 Sim | Bicicleta | Sim, regularmante | Não | Sim | Sim, mas por vezes podem colocar o condutor em situações fora do seu controlo/perigo Sim | Sim | Um comando possível de prender ao conjunto frontal Alertar a presença do veículo na estrada
2021/10/17 00:16:40 | 36 Sim | Trotinete | Sim, mas raramente | Sim | Sim | Sim, mas por vezes podem colocar o condutor em situações fora do seu controlo/perigo Sim | Sim | Um comando possível de prender ao conjunto frontal Sinalizar curvas, Sinalizar travagem do veículo, Alertar a presença do veículo na estrada
2021/10/17 00:20:59 18 anos | Não | Sim, mas raramente | Sim | Não | Não | Sim | Um comando possível de prender ao conjunto frontal Sinalizar travagem do veículo
2021/10/17 00:21:49 | 19 Sim | Bicicleta | Não | Não | Não | | Sim | Sim | Ambos | Alertar a presença do veículo na estrada
2021/10/17 00:51:49 | 18 Não | | Não | Não | Não | | Sim | Sim | Ambos | Sinalizar curvas, Sinalizar travagem do veículo, Alertar a presença do veículo na estrada
2021/10/17 00:52:15 | 20 Não | Sim, mas raramente | Não | Não | Não | Sim | Um comando possível de prender ao conjunto frontal Sinalizar curvas
2021/10/17 00:53:40 | 18 Não | Sim, mas raramente | Não | Sim | Sim, mas por vezes podem colocar o condutor em situações fora do seu controlo/perigo Não | Sim | Um comando possível de prender ao conjunto frontal Sinalizar curvas
2021/10/17 00:57:54 | 19 Não | Não | Não | Sim | Sim, mas por vezes podem colocar o condutor em situações fora do seu controlo/perigo Sim | Sim | Um comando possível de prender ao conjunto frontal Sinalizar curvas, Sinalizar travagem do veículo, Alertar a presença do veículo na estrada
2021/10/17 00:59:45 | 19 Não | Não | Não | Não | Sim | Sim | Um comando possível de prender ao conjunto frontal Sinalizar curvas, Sinalizar travagem do veículo, Alertar a presença do veículo na estrada
2021/10/17 01:00:31 | 17 Não | Não | Não | Sim | Sim, mas por vezes podem colocar o condutor em situações fora do seu controlo/perigo Sim | Sim | Um comando possível de prender ao conjunto frontal Sinalizar curvas, Alertar a presença do veículo na estrada
2021/10/17 01:09:08 | 18 Não | | Não | Não | Sim | Não | Sim | Sim | Ambos | Sinalizar curvas
2021/10/17 01:11:37 | 19 Não | Não | Não | Sim | Sim, mas por vezes podem colocar o condutor em situações fora do seu controlo/perigo Não | Sim | Um comando possível de prender ao conjunto frontal Sinalizar curvas, Alertar a presença do veículo na estrada
2021/10/17 01:15:00 | 19 Não | | Sim, mas raramente | Sim | Não | | Sim | Sim | Ambos | Sinalizar travagem do veículo
2021/10/17 01:36:12 | 17 Sim | bicicleta | Sim, regularmante | Sim | Sim | Sim, mas por vezes podem colocar o condutor em situações fora do seu controlo/perigo Sim | Sim | Um comando possível de prender ao conjunto frontal Sinalizar curvas, Alertar a presença do veículo na estrada
2021/10/17 01:46:56 | 18 Não | | Não | Não | Não | | Sim | Sim | A partir do telémovel | Alertar a presença do veículo na estrada
2021/10/17 02:57:04 | 18 Sim | Eu andava de surfskate mas... já não á surfskate ;-; Sim, mas raramente | Sim | Sim | Sim, mas por vezes podem colocar o condutor em situações fora do seu controlo/perigo Sim | Sim | Um comando possível de prender ao conjunto frontal Sinalizar curvas, Sinalizar travagem do veículo
2021/10/17 06:34:45 | 40 Não | | Não | Não | Não | | Sim | Sim | Ambos | Sinalizar curvas, Sinalizar travagem do veículo, Alertar a presença do veículo na estrada
2021/10/17 07:36:05 | 45 Sim | Bicicleta. E trotinete | Sim, regularmante | Não | Sim | Não | Não | Sim | Ambos | Sinalizar curvas, Sinalizar travagem do veículo, Alertar a presença do veículo na estrada
2021/10/17 08:14:14 | 19 Não | Não | Não | Sim | Sim, mas por vezes podem colocar o condutor em situações fora do seu controlo/perigo Não | Sim | Um comando possível de prender ao conjunto frontal Sinalizar curvas, Sinalizar travagem do veículo, Alertar a presença do veículo na estrada
2021/10/17 08:19:36 | 18 Não | | Não | Não | Sim | Sim | Não | Sim | Ambos | Sinalizar travagem do veículo, Alertar a presença do veículo na estrada
2021/10/17 08:23:57 | 18 Não | Não | Não | Sim | Sim | Não | Não | Um comando possível de prender ao conjunto frontal Sinalizar curvas
2021/10/17 08:38:54 | 37 Não | Não | Não | Sim | Sim, mas por vezes podem colocar o condutor em situações fora do seu controlo/perigo Não | Sim | Um comando possível de prender ao conjunto frontal Sinalizar curvas, Sinalizar travagem do veículo, Alertar a presença do veículo na estrada
2021/10/17 08:40:16 | 18 Não | Sim, mas raramente | Não | Não | Sim | Sim | Um comando possível de prender ao conjunto frontal Sinalizar curvas, Sinalizar travagem do veículo, Alertar a presença do veículo na estrada
2021/10/17 08:53:42 | 20 Não | Não | Não | Não | Não | Sim | Um comando possível de prender ao conjunto frontal Sinalizar curvas, Sinalizar travagem do veículo, Alertar a presença do veículo na estrada
2021/10/17 09:00:15 | 21 Não | Não | Não | Sim | Sim, mas por vezes podem colocar o condutor em situações fora do seu controlo/perigo Sim | Sim | Ambos | Sinalizar curvas, Sinalizar travagem do veículo
2021/10/17 09:22:53 | 18 Não | Não | Não | Sim | Não | Não | Sim | Um comando possível de prender ao conjunto frontal Sinalizar curvas, Sinalizar travagem do veículo, Alertar a presença do veículo na estrada
2021/10/17 10:13:46 | 18 Não | Não | Sim | Sim | Sim, mas por vezes podem colocar o condutor em situações fora do seu controlo/perigo Não | Sim | Um comando possível de prender ao conjunto frontal Sinalizar curvas, Sinalizar travagem do veículo
2021/10/17 10:33:12 | 18 Não | Sim, mas raramente | Não | Não | Sim, mas por vezes podem colocar o condutor em situações fora do seu controlo/perigo Não | Não | Um comando possível de prender ao conjunto frontal Sinalizar curvas, Sinalizar travagem do veículo, Alertar a presença do veículo na estrada
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

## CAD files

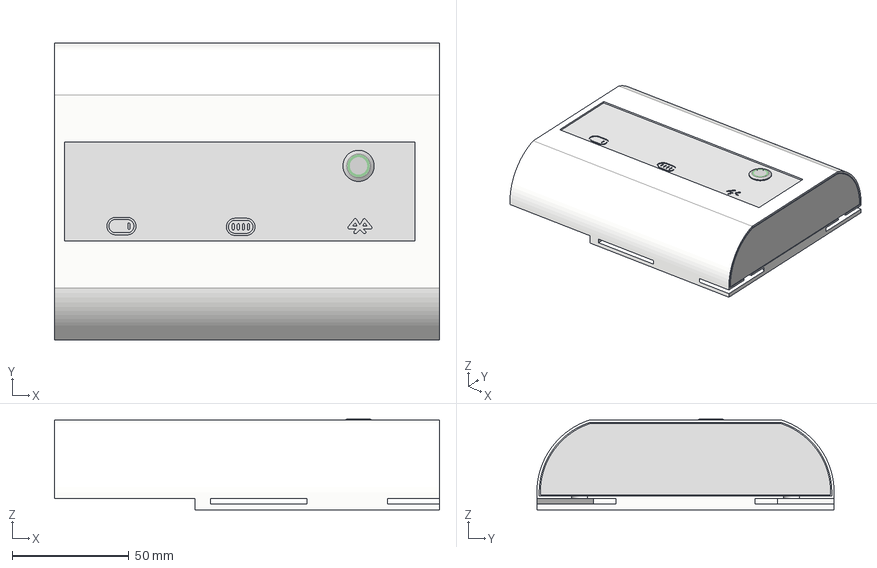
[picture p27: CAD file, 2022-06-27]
CAD/MainBoard/MainBoard v33.3mf
165.1 x 127.5 x 39.0 mm
BT
Battery
Bend 90 (1) x 6
Bend 90 x 6
CHRG
Dumet1 x 6
Dumet2 x 6
External Lead2 (1) x 6
External Lead2 x 6
Glass Sleeve x 6
Internal Dumet Wire1 x 6
Internal Dumet Wire2 x 6
Lead Chamfer2 (1) x 6
Lead Chamfer2 x 6
Ohmic Contact x 6
STBY
Silicon Die x 6

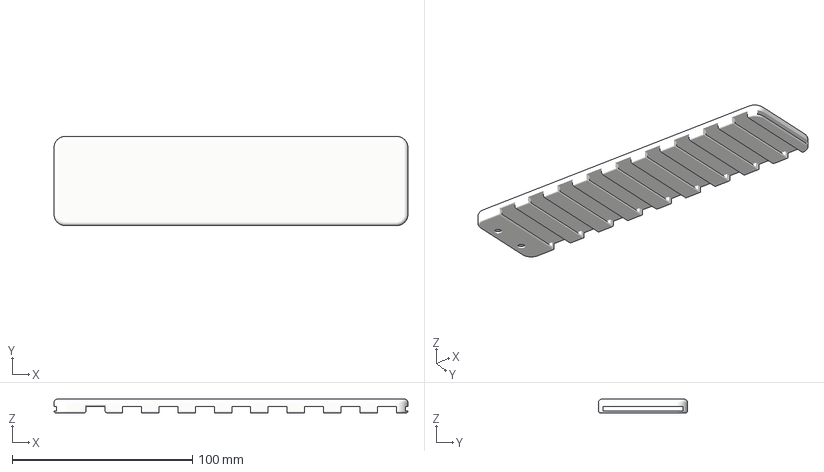
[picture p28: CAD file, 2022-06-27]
CAD/Blinkers/Shoulder LEDs v17.3mf
196.3 x 49.6 x 7.67 mm

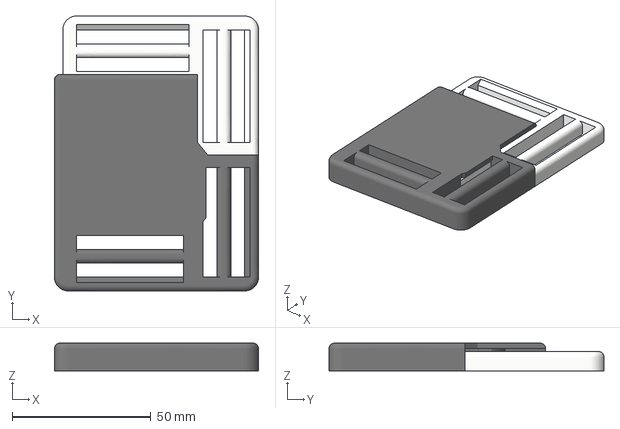
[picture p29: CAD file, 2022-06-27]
CAD/Buckler/Buckle v11.3mf
73.5 x 99.0 x 10.0 mm

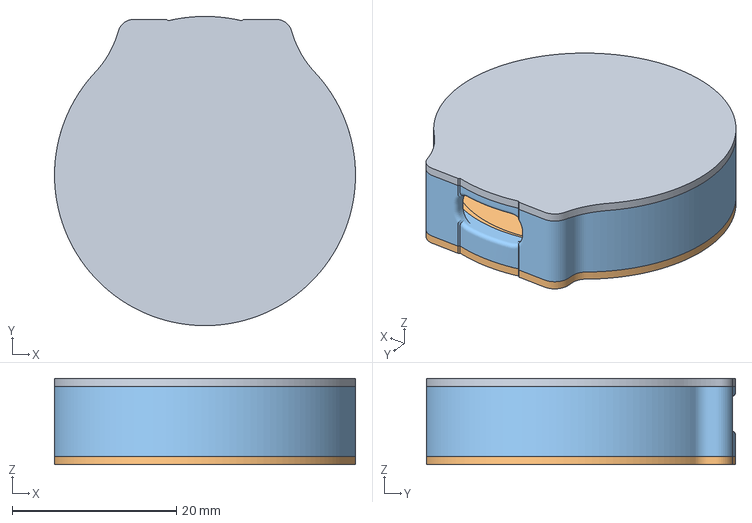
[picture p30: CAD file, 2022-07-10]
CAD/Charger/Charger v6.3mf
36.7 x 37.7 x 10.5 mm

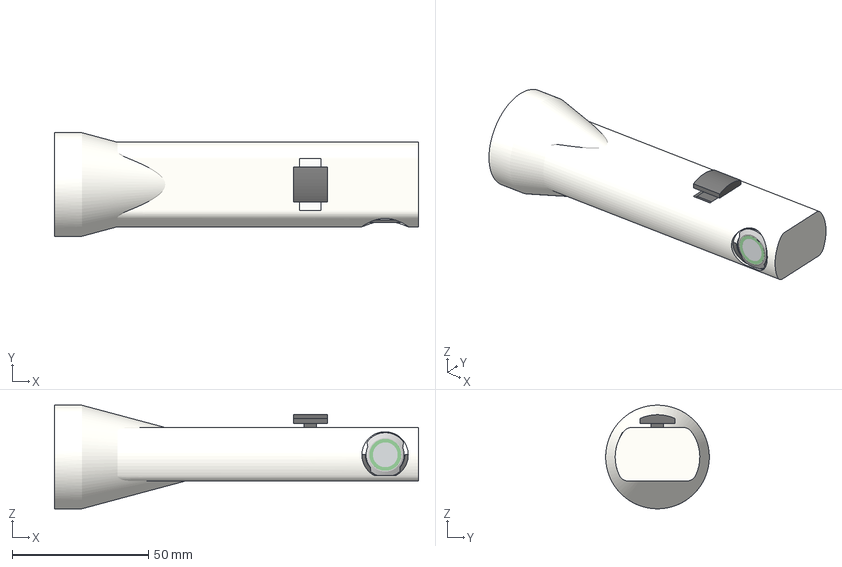
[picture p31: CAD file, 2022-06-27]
CAD/Controller/Controller v42.3mf
133.4 x 38.0 x 38.0 mm
Bottom
Dumet1 x 6
Dumet2 x 6
Glass Sleeve x 6
Lead Chamfer1 x 6
Lead Chamfer2 x 6
Ohmic Contact x 6
Silicon Die x 6
Top

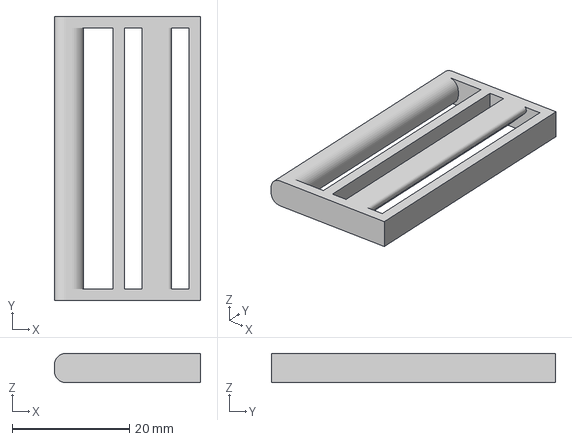
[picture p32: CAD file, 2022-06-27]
CAD/Fastner/Fastner v2.3mf
25.0 x 48.5 x 5.00 mm

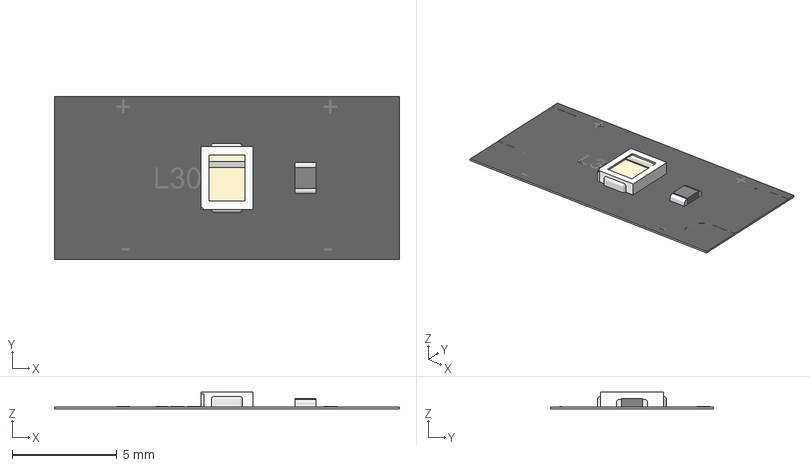
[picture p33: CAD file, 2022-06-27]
CAD/LED D100/LED D100 v1.3mf
16.5 x 7.80 x 0.8 mm

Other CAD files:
CAD/Blinkers/Shoulder LEDs v17.f3z
CAD/Buckler/Bickle v11.f3d
CAD/Charger/Charger v7.f3z
CAD/Coil/Coil v11.f3d
CAD/Fastner/tightening v2.f3d
CAD/LED RGB/m v1.f3d

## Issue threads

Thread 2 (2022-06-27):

Unpredictable behaviour on some connections

PedroTorrado, 2022-06-27:
When connecting the Controller and Mainboard, sometimes the controller sends random "right" signals to the Mainboard, many times this is solved by charging the device, not sure if that's the source of the problem still.

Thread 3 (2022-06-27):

No battery controll

PedroTorrado, 2022-06-27:
There is no way to identify if the battery in the device is low and when to charge it apart from the device not behaving as intended or not turning on at all.

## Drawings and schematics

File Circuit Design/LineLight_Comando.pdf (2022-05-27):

HC05

## ON/OFF Switch

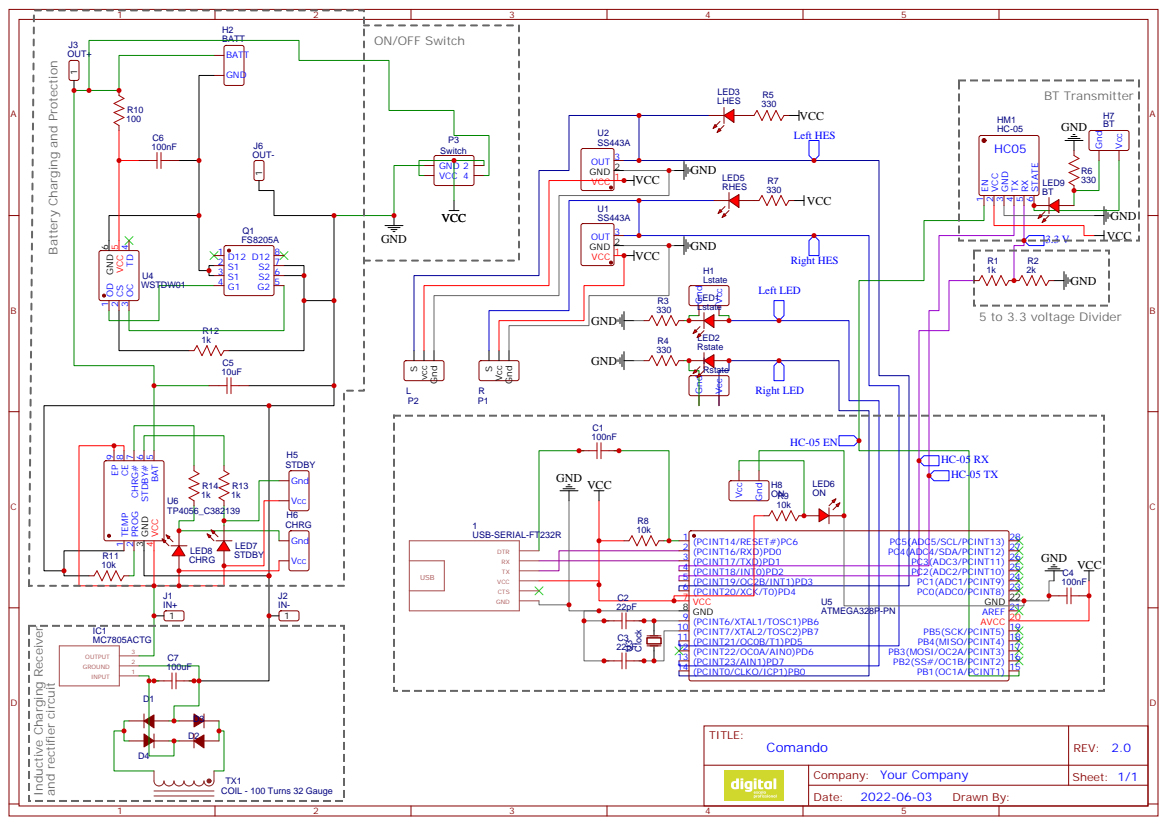
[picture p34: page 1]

and rectifier circuit Battery Charging and Protection

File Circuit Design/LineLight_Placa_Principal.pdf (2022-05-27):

HC05

## ON/OFF Switch

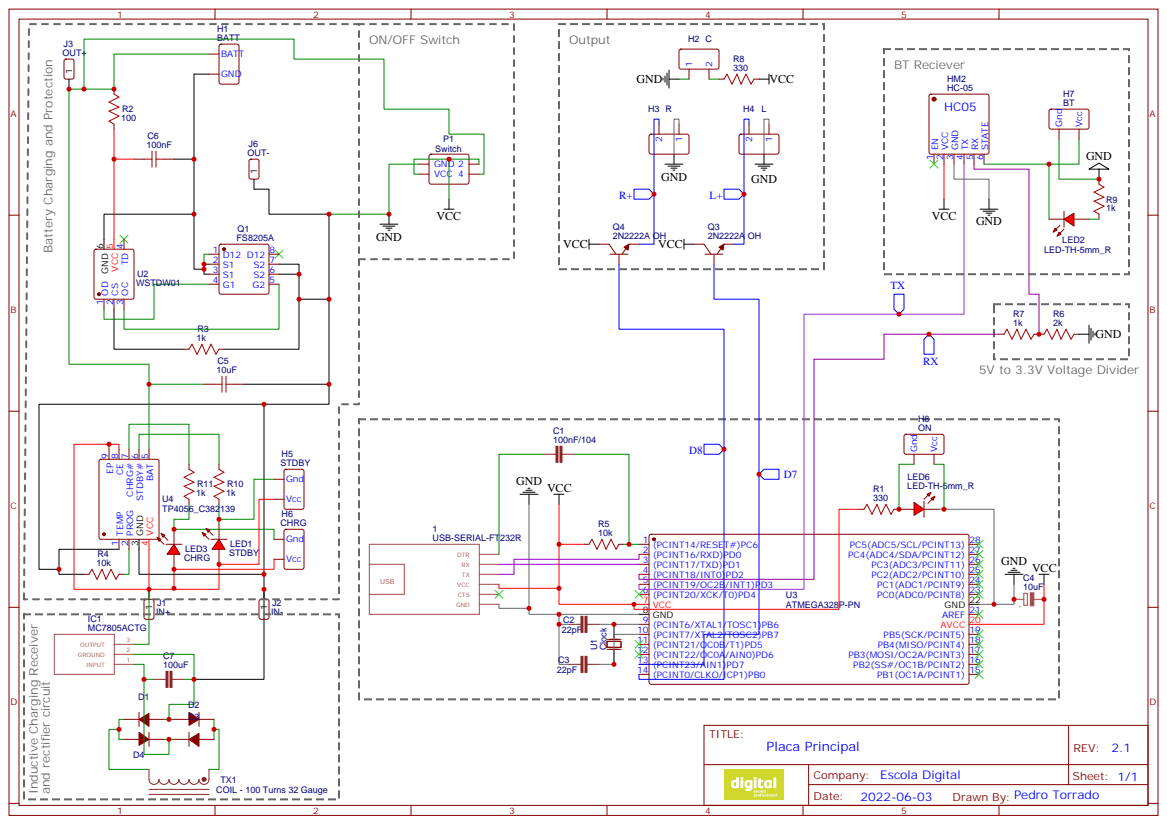
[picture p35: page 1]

Battery Charging and Protection

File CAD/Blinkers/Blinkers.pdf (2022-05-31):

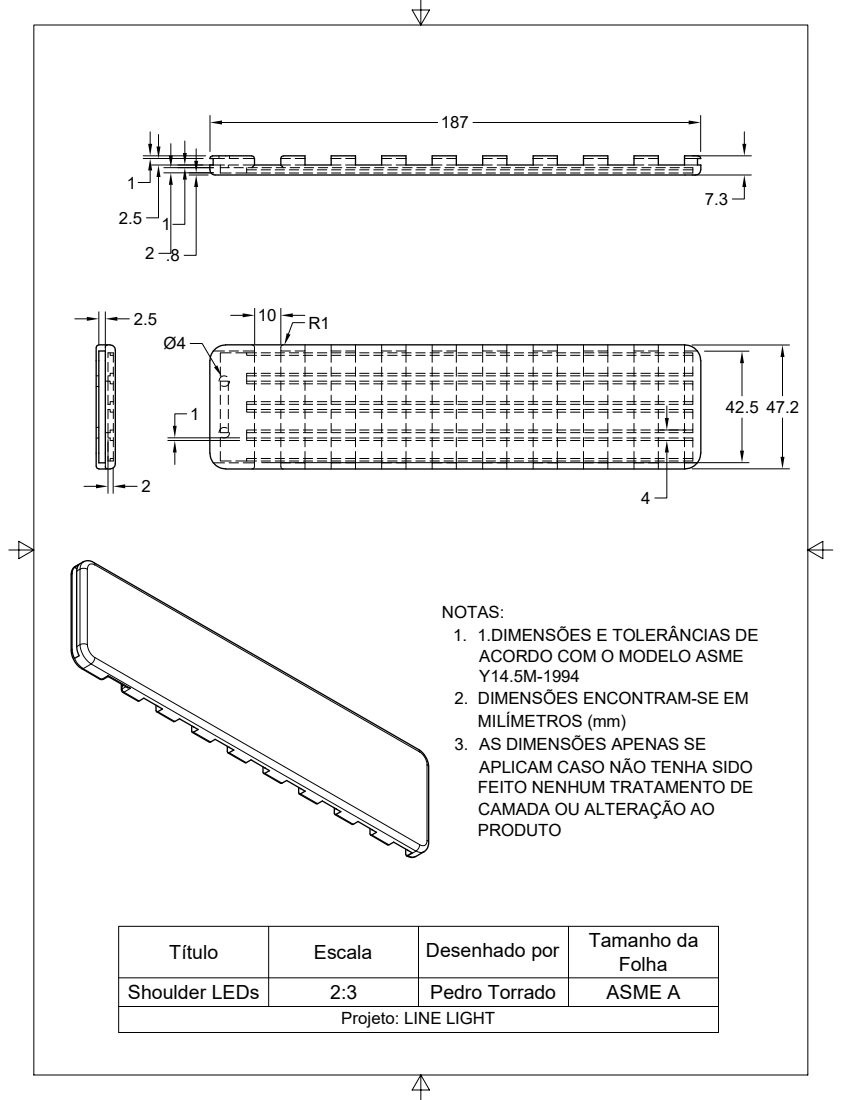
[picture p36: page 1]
Shoulder LEDs; Pedro Torrado; ASME A; Título; Escala; Desenhado por; Tamanho da; Folha

NOTAS:
1. 1.DIMENSÕES E TOLERÂNCIAS DE
ACORDO COM O MODELO ASME
2. DIMENSÕES ENCONTRAM-SE EM
MILÍMETROS (mm)
3. AS DIMENSÕES APENAS SE
APLICAM CASO NÃO TENHA SIDO
FEITO NENHUM TRATAMENTO DE
CAMADA OU ALTERAÇÃO AO
PRODUTO

Projeto: LINE LIGHT

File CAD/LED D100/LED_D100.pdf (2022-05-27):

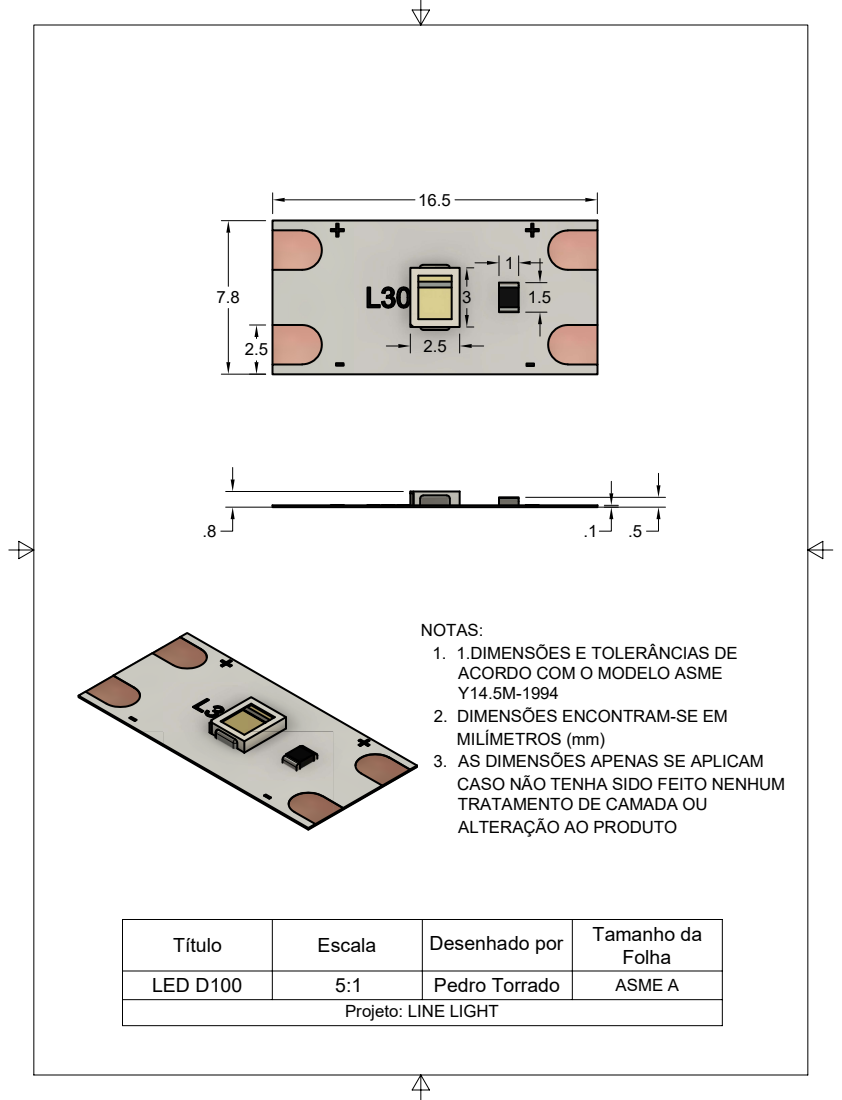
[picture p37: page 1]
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

Título | Escala | Desenhado por | Tamanho da Folha

LED D100 | 5:1 | Pedro Torrado | ASME A

Projeto: LINE LIGHT

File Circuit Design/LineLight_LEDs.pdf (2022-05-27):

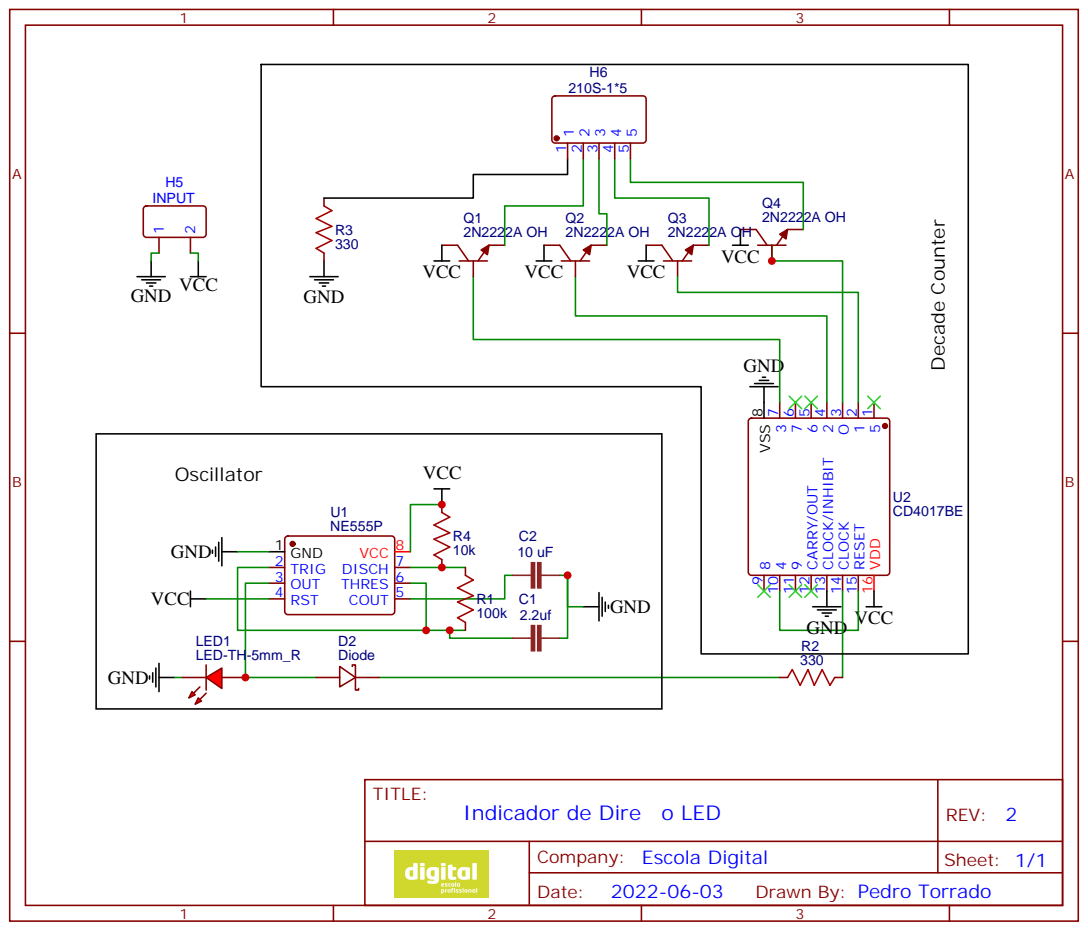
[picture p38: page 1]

Drawn By: Pedro Torrado

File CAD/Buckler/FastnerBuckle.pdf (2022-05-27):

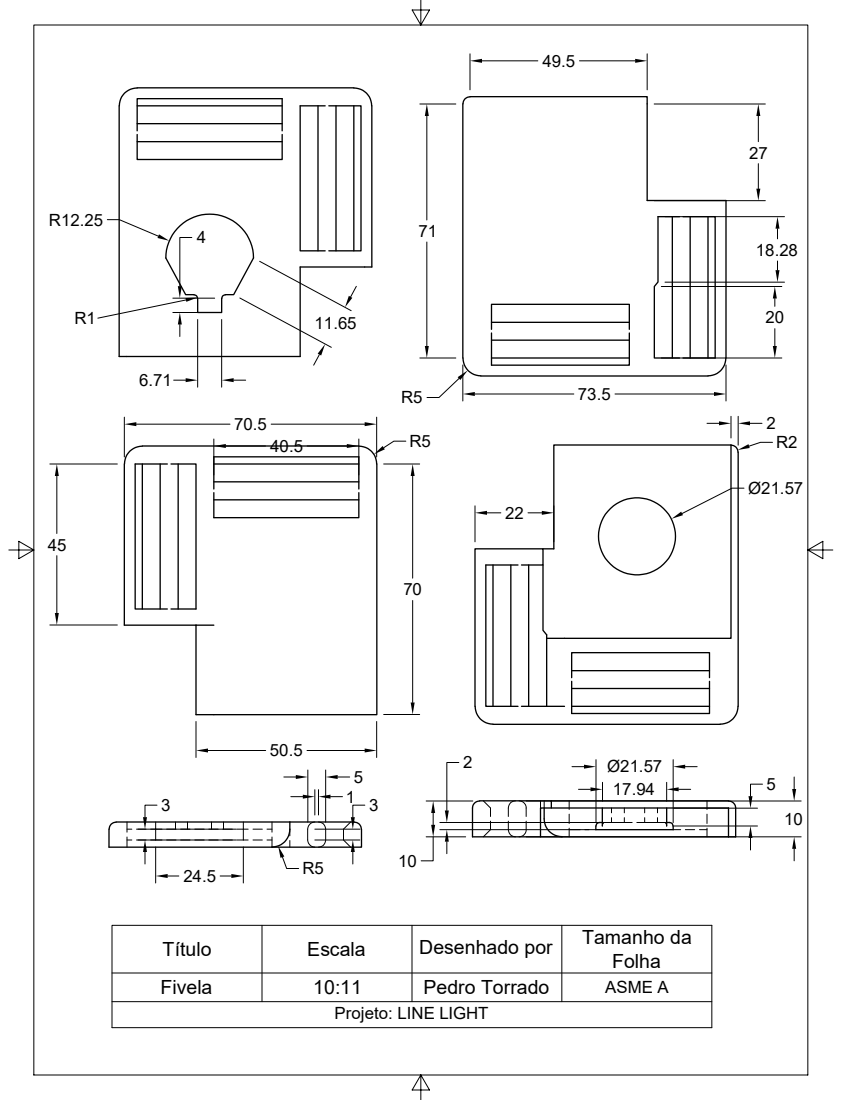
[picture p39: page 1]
Fivela; Pedro Torrado; ASME A; Título; Escala; Desenhado por; Tamanho da; Folha

Projeto: LINE LIGHT

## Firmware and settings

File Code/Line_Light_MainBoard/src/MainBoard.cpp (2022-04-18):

//RV_2.2

//Code for arduino nano to function as a Bluetooth Slave and receiver to control a group of LEDs to work as Blinkers and road lights
//Revision 2.1 of the main board of the Reciever
//Code written and edited by Pedro Torrado

//Differences from last Revision (1.1)
  //Improved code and performance
  //Improved comments to easier understanding
    //MOST IMPORTANT//
  //Created two-way signal communication which makes possible :
  //Verification of the signal sent through Serial Monitor and visible LEDs to Warn the user in case the communication didn't work as planned

//Differences 2.0
  //Command '0' added for toubleshooting
  //Command '3' removed

//Differences 2.1
  //Connection confirmation
  //leftstate and rightstate functions created
  //Command '9' added to check output status and send validation data

#include <Arduino.h>
#include <SoftwareSerial.h>
SoftwareSerial bt(3, 2);  //RX, TX

#define left_led 7
#define right_led 8

int i;
int left_state = 1;
int right_state = 1;
int lr_state = 0;
int new_left_state = 1;
int new_right_state = 1;
int new_lr_state = 0;
char serial_command;

void setup() {
  pinMode(3, INPUT);
  pinMode(2, OUTPUT);

  pinMode(left_led, OUTPUT);  // sets the digital pin 7 as output
  pinMode(right_led, OUTPUT);  // sets the digital pin 8 as output

  Serial.begin(9600);
  bt.begin(9600);

  Serial.println("Start Blnkrs");
}

void leftstate(){
  if(left_state == 0){
    bt.write(10);
    Serial.println("Verification Code Sent: 10");
  }
  else if(left_state == 1){
    bt.write(11);
    Serial.println("Verification Code Sent: 11");
  }
  else {
    Serial.println("Input error : state was changed but the result isn't valid");
  }
}

void rightstate(){
  if (right_state == 1){
    bt.write(21);
    Serial.println("Verification Code Sent: 21");
  }
  else if (right_state == 0){
    bt.write(20);
    Serial.println("Verification Code Sent: 20");
  }
  else{
    Serial.println("Input error : state was changed but the result isn't valid");
  }
}

void loop() {

  //include both functions for verification
  int leftstate();
  int rightstate();

  if(bt.available()>0 or Serial.available()){

    char command = bt.read();
    serial_command = Serial.read();

    if (command != ""){
      Serial.println(command);
    }
    else if (serial_command != ""){
      Serial.println(serial_command);
    }

    if(command == '9' or serial_command == '9'){
      Serial.println("Device Paired");
      bt.write(91); // Verification Code sent to Controller to verify connection
      leftstate();
      rightstate();
    }

    else if (command == '0' or serial_command == '0'){

      //used to troubleshoot communication between modules
      //sends and receives all the information needed for two-way communication and hardware check
      //can't be achieved through hardware

      if(new_lr_state == 1){
        digitalWrite(left_led, HIGH);
        digitalWrite(right_led, HIGH);
        Serial.println("LEFT_&_RIGHT_HIGH");
        lr_state = 0;
        right_state = 0;
        left_state = 0;
      }

      else if(new_lr_state == 0){
        digitalWrite(left_led, LOW);
        digitalWrite(right_led, LOW);
        Serial.println("LEFT_&_RIGHT_LOW");
        lr_state = 1;
        left_state = 1;
        right_state = 1;
      }

      new_lr_state = lr_state;

      if (lr_state == 1){
        bt.write(11); // Verification Code sent to Controller to left Blinker
        bt.write(21); // Verification Code sent to Controller to Right Blinker
      }
      else if (lr_state == 0){
        bt.write(10); // Verification Code sent to Controller to left Blinker
        bt.write(20); // Verification Code sent to Controller to Right Blinker
      }
      else{
        Serial.println("Input error : the state was changed but the result isn't valid");
      }
    }

    if (command == '1' or serial_command == '1') {

      if (new_left_state == 1) {
        digitalWrite(left_led, HIGH);  // sets the digital pin 7 ON
        Serial.println("LEFT_HIGH");   // print on serial monitor the pin mode
        left_state = 0;
      }
      else if (new_left_state == 0) {
        digitalWrite(left_led, LOW);  // sets the digital pin 7 OFF
        Serial.println("LEFT_LOW");   // print on serial monitor the pin mode
        left_state = 1;
      }
      new_left_state = left_state;
      leftstate();
    }

    if (command == '2' or serial_command == '2') {

      if (new_right_state == 1) {
        digitalWrite(right_led, HIGH);  // sets the digital pin 7 ON
        Serial.println("RIGHT_HIGH");   // print on serial monitor the pin mode
        right_state = 0;
      }

      else if (new_right_state == 0) {
        digitalWrite(right_led, LOW);  // sets the digital pin 7 OFF
        Serial.println("RIGHT_LOW");   // print on serial monitor the pin mode
        right_state = 1;
      }
      new_right_state = right_state;
      rightstate();
    }
  }
}

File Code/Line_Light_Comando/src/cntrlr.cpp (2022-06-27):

//RV_2.4

//Code for arduino nano to function as a Bluetooth Master in order to controll the Blinkers main board
//Revision 2.3 of the main board of the Controller
//Code writen and edited by Pedro Torrado

//Diferences from last Revision (1.2 - 2.0)
  //Improved code and performance
  //Improved comments in order to easier understanding
    //MOST IMPORTANT//
  //Created two way signal communication which makes possible :
  //Verification of the signal sent through Serial Monitor and visable LEDs in order to Warn the user in case the communication didn't work as planned

//Differences from 2.0
  //Verification turned into a function in order to reduce delay between comunication and avoid delays

//Differences from 2.1
  //delay functions devided in order to have time to recieve the information without having to wait the full 1000ms

//Differences from 2.2
  //Verification after checking bluetooth signal in order to have better response to led state commands from slave

//Differences from 2.3
  //Connection confirmation
  //Variable request in order to verify the led status

#include <Arduino.h>
#include <SoftwareSerial.h>
SoftwareSerial bt(2, 3);  //RX, TX

#define right_hes 4
#define left_hes 5
#define bt_enable 9
#define left_led 7
#define right_led 8

int left_state = 1;
int right_state = 1;
int verification_code;

void setup() {
  //Bluetooth RX and TX defined
  pinMode(2, INPUT);
  pinMode(3, OUTPUT);

  //HC06 enable pin set to LOW
  pinMode(9, OUTPUT);
  digitalWrite(bt_enable, LOW);
  bt.begin(9600);

  //Hall Effect Sensors defined
  pinMode(right_hes, INPUT);
  pinMode(left_hes, INPUT);

  //Verification LEDs defined
  pinMode(left_led, OUTPUT);
  pinMode(right_led, OUTPUT);

  Serial.begin(9600);
  Serial.println("Start Cntrlr");

  bt.write('9');
  Serial.println("Pairing...");

  left_state = digitalRead(left_hes);
  right_state = digitalRead(right_hes);
}

void verification(){

  if (bt.available()>0) {
    verification_code = bt.read();
    //Serial.println(verification_code); //Shows the byte sent from the slave for troubleshooting

    if(verification_code == 10){
      digitalWrite(left_led, HIGH);
      //Shows what type of confirmation it has recieved, for troubleshooting in case of led problems
      //Serial.println("left_confirmed_high");
    }
    else if(verification_code == 11){
      digitalWrite(left_led, LOW);
      //Serial.println("left_confirmed_low");
    }
    else if(verification_code == 20){
      digitalWrite(right_led, HIGH);
      //Serial.println("right_confirmed_high");
    }
    else if(verification_code == 21){
      digitalWrite(right_led, LOW);
      //Serial.println("right_confirmed_low");
    }
    else if(verification_code == 91){
      Serial.println("Device Paired");
    }

    else{
      Serial.println("Input error : Not intended result or verification");
    }

  }
  else{
    verification_code = 00;
  }

}

void loop() {

  left_state = digitalRead(left_hes);
  right_state = digitalRead(right_hes);

  if (bt.available()>0) {
    verification();
  }

  //Show the output in Serial for troubleshooting
  //Serial.println(right_state);
  if (Serial.available()){
    bt.write(Serial.read());
  }

  else if (right_state == LOW) {
    Serial.println("Right");
    //Show the output in Serial for troubleshooting
    //Serial.println('2');
    bt.write('2');
    delay(200);
  }

  else if (left_state == LOW) {
    Serial.println("Left");
    //Show the output in Serial for troubleshooting
    //Serial.println('1');
    bt.write('1');
    delay(200);
  }

  else{}

}

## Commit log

2021-11-20 <Arduino.h>
    #include <Arduino.h> added in order to use Platform.io to upload to the Atmega328p without the Arduino IDE
2021-11-20 Circuit Files Added
    Circuit Design and Code folders and organizes.
    Added and circuit designs added
2021-11-22 Folders and MainBoard (3d)
    Created folder 3d Design
    Created folder 3d Design/Controller
    Created folder 3d Design/LED
    Created folder 3d Design/MainBoard
    (3d Design/Mainboard) Added to files:
    Encloser v16.f3z
    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
    [Controller PCB v5.stl, LEDPCB v1.stl, MainBoard v3.f3z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]
2021-11-22 STL PCB Folders Deleted
    [Controller PCB v5.stl, LEDPCB v1.stl]
2021-11-23 Create mount v6_img.png
2021-11-27 Removed 3d models
    [Controller PCB v5.stl, LEDPCB v1.stl, MainBoard v3.f3z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]
2022-01-03 Added LIPO charger circuits
2022-05-27 Atualizado para entrega final
2022-06-22 Added 3mf file for Buckle
    [Buckle v11.3mf]
2022-06-22 Added Fastner 3mf
    [Fastner v2.3mf]
2022-06-22 Added Controller 3mf
    [Controller v42.3mf]
2022-06-22 Added LED D100 3mf
    [LED D100 v1.3mf]
2022-06-22 Added f3d
    [m v1.f3d]
2022-06-22 Added 3mf
    [Shoulder LEDs v17.3mf]
2022-06-23 Added Fusion 360 file
    [Bickle v11.f3d, Coil v11.f3d, Shoulder LEDs v17.f3z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]
2022-06-24 New Component for Fabrication
    [CoilWinder.FCStd]
2022-06-24 Updated File
    [CoilWinder.FCStd]
2022-06-27 Updated object
    [CoilWinder.FCStd]
2022-07-10 Removed Winder
    [CoilWinder.FCStd]
2022-07-10 Create Wireless Charge.FCStd
    [Wireless Charge.FCStd]
2022-07-10 updated Charger
    [Wireless Charge.FCStd]
2022-07-10 Change to F360
    [Charger v1.f3d, Wireless Charge.FCStd]
2022-07-10 Update Charger v1.f3d
    [Charger v1.f3d]
2022-07-10 first export
    [Charger v4.f3z, Charger v5.3mf]
2022-07-10 Updated Sizes
    [Charger v1.f3d, Charger v4.f3z, Charger v5.3mf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]
